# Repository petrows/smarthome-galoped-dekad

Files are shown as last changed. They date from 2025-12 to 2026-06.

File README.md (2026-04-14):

# Galoped-dekad

Vintage analog indicator with modern MCU and Tasmota.

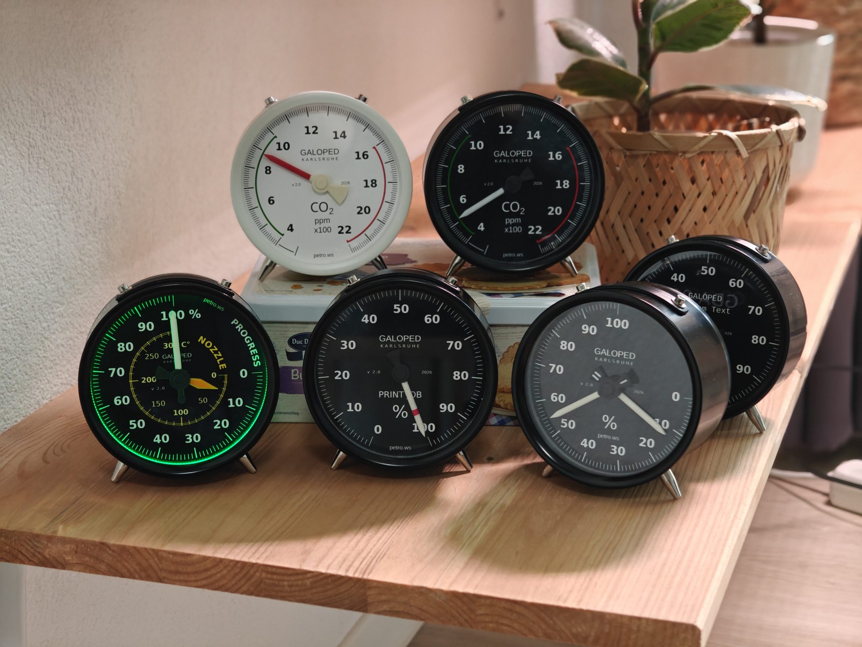
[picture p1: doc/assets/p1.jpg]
Device


This device is a universal desktop indicator with nice exterrior and full open source nature. Based on ESP32-WROOM32E SoC module, VID6608 automotive gauge driver and X27-168 automotive gauge stepper motor.

* Analog indication with needle, resolution is 3840 steps;
* Support to drive 2 motors within included PCB;
* On-board sensors support: SenseAir S8 for Co₂, BMP280+AHTO20 for Temperature, Pressure and Humidity readings and many others;
* WiFi connectivity;
* Backlight: dimmable retro-filament and addressed RGB supported;
* Easy customisation to display anything else, from internal or external data source;
* Designed to run Tasmota directly: WebUI, MQTT, Smart-home integration and etc;
* 3D Printers status readings (i.e. temperature and progress) and display - for BambuLab and Octoprint;

## Buy device

I have some devices available on Etsy: https://www.etsy.com/de-en/shop/PetroWSDE

## Device variants

Device has several veriants built:

* [CO2 and Cliamte instrument](doc/device-co2.md)
* [3D Printer temperature + progress](doc/device-3dp.md)

## Changelog

* Device version 1: [Version-1 history branch](https://github.com/petrows/smarthome-galoped-dekad/tree/Version-1)
* Device version 2: This readme

### Changes in Version 2:

* Complete new case parts with optimized design:
    * Backlight and main part are assembled before case installation (significally reduces assembly effort)
    * Improved structure stability
* Only one PCB for now is required, drive enclosure is part of case for now
* Fixed design issues for PCB (missing pulldown resistors, connectors redesign)
* New USB-C power socket with USB-C-C cables support
* Complete rework of RGB backlight, removed LED artifacts and glare
* Complete firmware rework (autoexec.bat is not required anymore, fully integrated logic and UI)

## Project information

* [How to configure device](doc/fw-config.md)
* [How to command device](doc/fw-command.md)

## Device components

This repo contains full sources for this device:

* [CAD and STL models for device enclosure](case)
* [Datasheets for all components used](datasheet)
* [Firmare sources and configuration](firmware)
* [Gauge graphics](gauge)
* [Device schematics](schematic)

### External components

* Metal enclosure and glass is taken from [Ikea Dekad](https://www.ikea.com/de/de/p/dekad-wecker-schwarz-30540479/)

### Backlight

* Retro backlight version: 3V flexible LED filament strip (300mm)
* RGB baklight version: 252 mm (40 LED's) of 2.7 mm WS2812b addressed led strip

I dont assembly Retro backlight version by default anymore. RGB Backlight looks and works better for now in version 2.

## PCB and Schematics

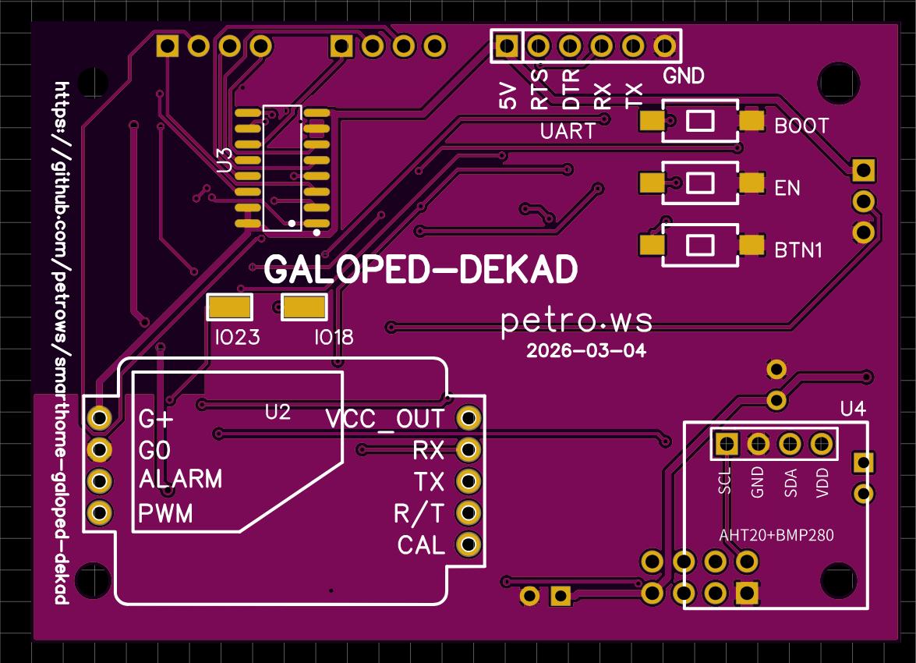
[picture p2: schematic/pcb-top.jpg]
PCB top


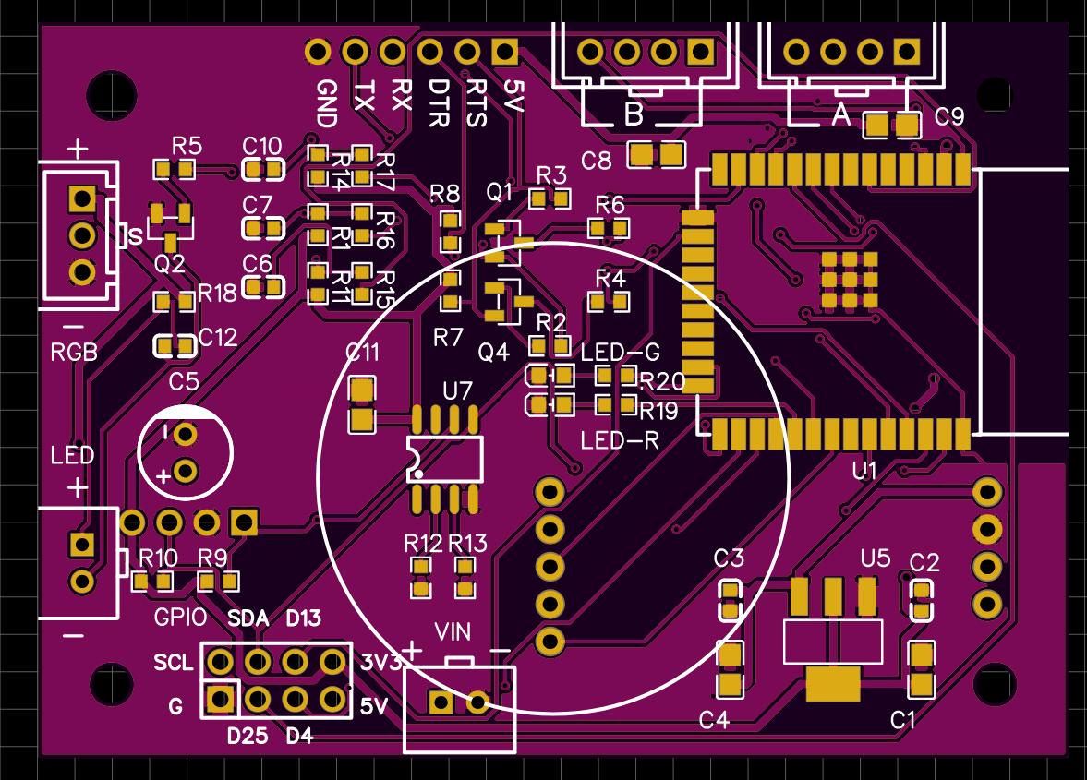
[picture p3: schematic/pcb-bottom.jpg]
PCB bottom


Made in EasyEDA Web project:

* [MCU board](https://oshwlab.com/petrows/galoped-dekad)

## Firmware

Firmware is based on [Tasmota](https://tasmota.github.io) with many features included.

Download actual version at [Releases](https://github.com/petrows/smarthome-galoped-dekad/releases) page.

Device configuration: [Galoped firmware configuration](doc/fw-config.md).

Scripts are in [firmware configuration files](firmware).

## Device strucutre

Physical parts are designed in FreeCAD and provided as-is with STL files to print:

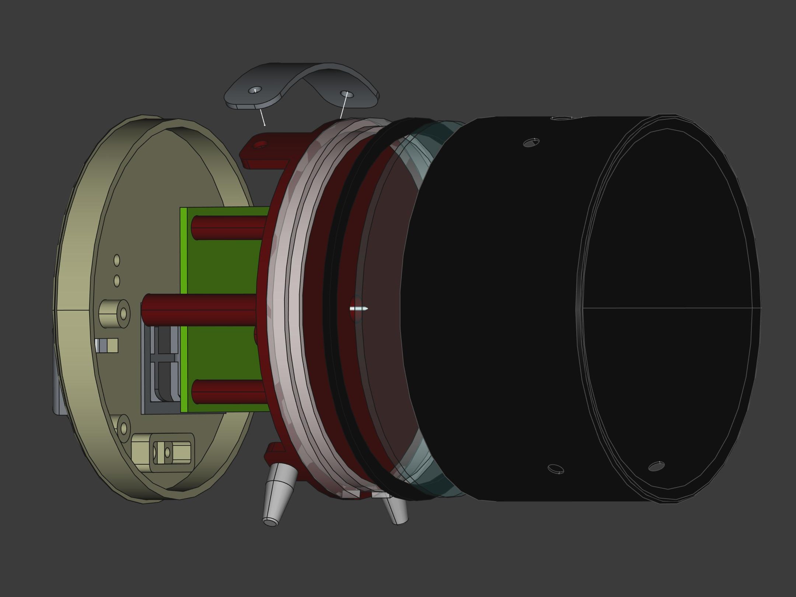
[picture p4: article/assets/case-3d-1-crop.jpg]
FreeCAD 3d view 1


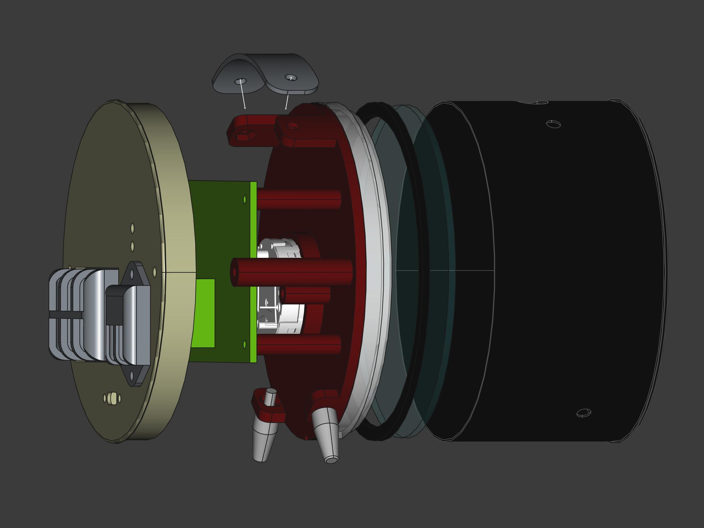
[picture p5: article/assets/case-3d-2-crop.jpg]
FreeCAD 3d view 2


## Assembly

See: [Assembly instructions](doc/assembly.md).

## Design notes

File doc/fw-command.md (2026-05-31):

# How to command device

This section describes, how to send commands to device.

## Primary gauge command

Original firmware defines new command `GalopedSetX Y`, where
`X` - gauge number starting from `1`, `Y` - target value *in gauge unuts*.

To use this command, device [Guage configuration](fw-config.md) is required.

Important: this command saves the state into FRAM memory (if present),
this is importnant to re-run correct zero procedure on power cycle.

Examples:

```ruby
# Set Gauge 1 to display 77% (units, i.e. percent, as defined in galoped.ini)
GalopedSet1 77

# Set Gauge 2 to display 32°C (units, i.e. degrees, as defined in galoped.ini)
GalopedSet2 32
```

Command can be issues via:

* Console (**Tools** -> **Console** or Serial console)
* Via HTTP, for example `http://<ip>/cm?cmnd=GalopedSet1%2023`
(use `%20` instead of space)
* MQTT

And other methods, see full list:
<https://tasmota.github.io/docs/Commands/#how-to-use-commands>

## Raw commands

Each unit has also raw commands to move: in steps or in procent from physical drive scale,
defined by VID6608 Tasmota driver. This commands ignore gauge settings in `galoped.ini`
and the **not** updating gauge position in FRAM - use with cauton.

Use following commands to control raw drive movement:

| Console Commands | Description | Values |
|---|---|---|
| `GaugeSet` | Set position in absolute steps | `0` - `3840`|
| `GaugeSetPercent`| Set position in percent | `0` - `100` |
| `GaugeZero` | Reset drive; optional argument is saved position | `0` - `3840`|

All commands have Drive suffix. If not set, it drives first motor. If set, it uses Drive number.
If suffix is `0` - it drives all motors. Examples:

* `GaugeZero3`: Reset drive number 3 with default reset routine;
* `GaugeZero2 751`: Reset drive number 2 with expected last position as `751`;
* `GaugeSet0 366`: Set all drives absolute position 366;
* `GaugeSetPercent 30`: Set drive number 1 position to 30%;

See full driver documentation here: <https://tasmota.github.io/docs/vid6608/> .

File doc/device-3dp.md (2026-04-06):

# Galoped (3D Printer version)

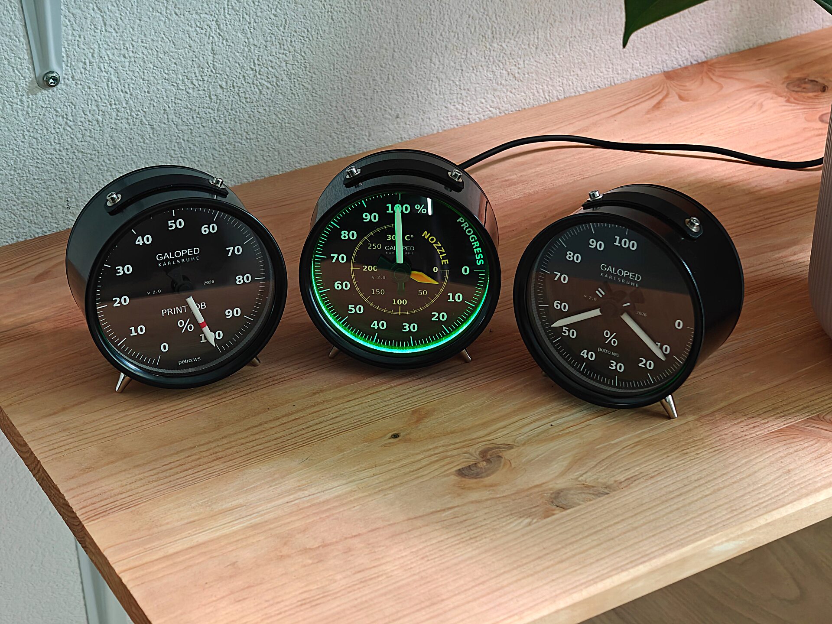
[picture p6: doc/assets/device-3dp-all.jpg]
Device


## Device specs

Device has customizations on top of base Galoped model:

* Device does not have any customization
* Sensors are not installed

## Configuration

Configuration for devices:

### Printer Temperature + Progress (Bi-Axial)

```ini
; galoped.ini
; Printer Temperature + Progress (Bi-Axial)
[galoped]
model = 3dp_tp
[gauge-1]
name = Temp
unit = C°
deg = 270
min = 0
max = 300
[gauge-2]
name = Progress
unit = %
deg = 270
min = 0
max = 100
```

## BambuLab printer status display

Firmware has module to read MQTT status report from BambuLab printers. To connect
such printer to gauge, you need to enable LAM mode and get Access key and know printer
address in LAN.

* [Enable developer mode in your printer](https://wiki.bambulab.com/en/knowledge-sharing/enable-developer-mode)
* Write down printer IP Address inside your home network
* Write down serial number of your printer

When done, you can configure Galoped's firmware to read data:

* Navigate to **Configuration** -> **Configure BambuLab**
* Enter required fields:
    * `Printer serial` - Serial number of your printer
    * `Printer IP` - Address of your printer in home network
    * `LAN Access code` - Access code for your printer

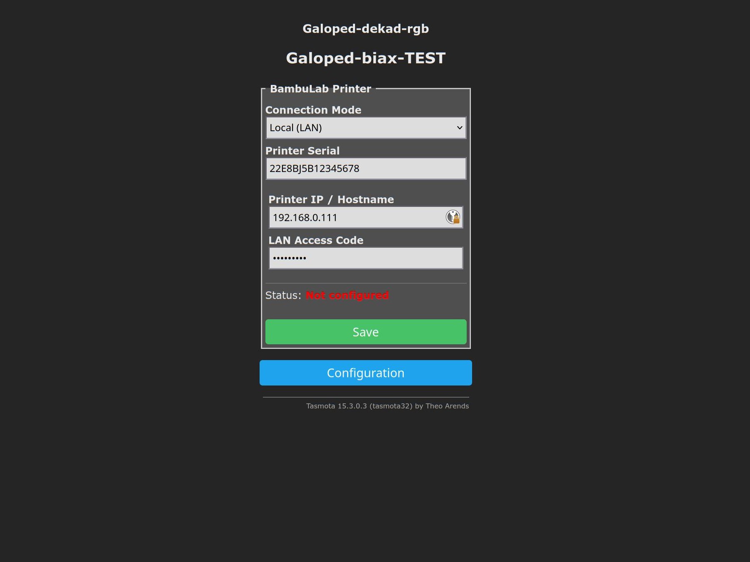
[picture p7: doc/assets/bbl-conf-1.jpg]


After configuration, please wait a few minutes, when data is read from printer,
you will see status at the index page:

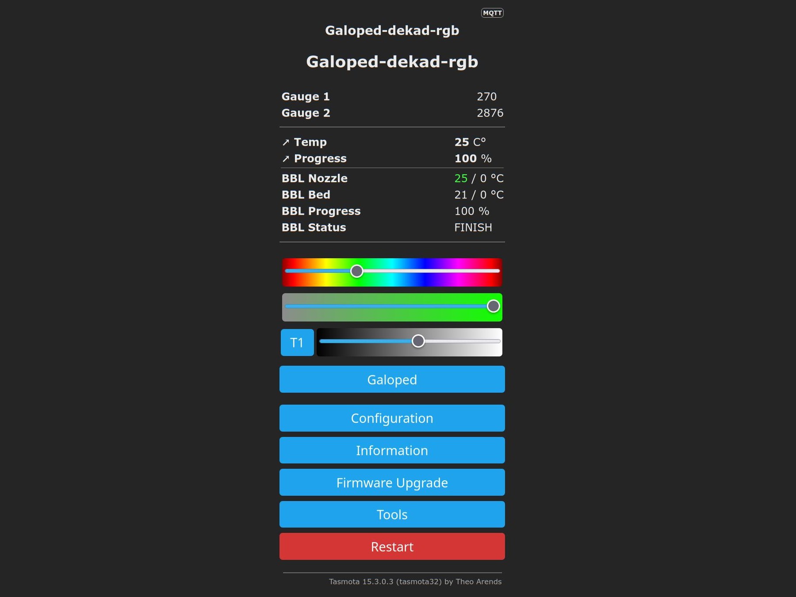
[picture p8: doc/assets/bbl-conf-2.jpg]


## Octoprint printer status display

Octoprint can be integrated using various ways.

Recommended option is to use common MQTT brocker and in this case you can configure Octoprint as follows:

```bash
# This command drives Gauge 1 to position 77%

mosquitto_pub -h <broker-ip> -u <username> -P <password> -t 'cmnd/galoped_ABCDEF/GalopedSet1' -m '77'
```

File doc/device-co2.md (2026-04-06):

# Galoped (CO2 version)

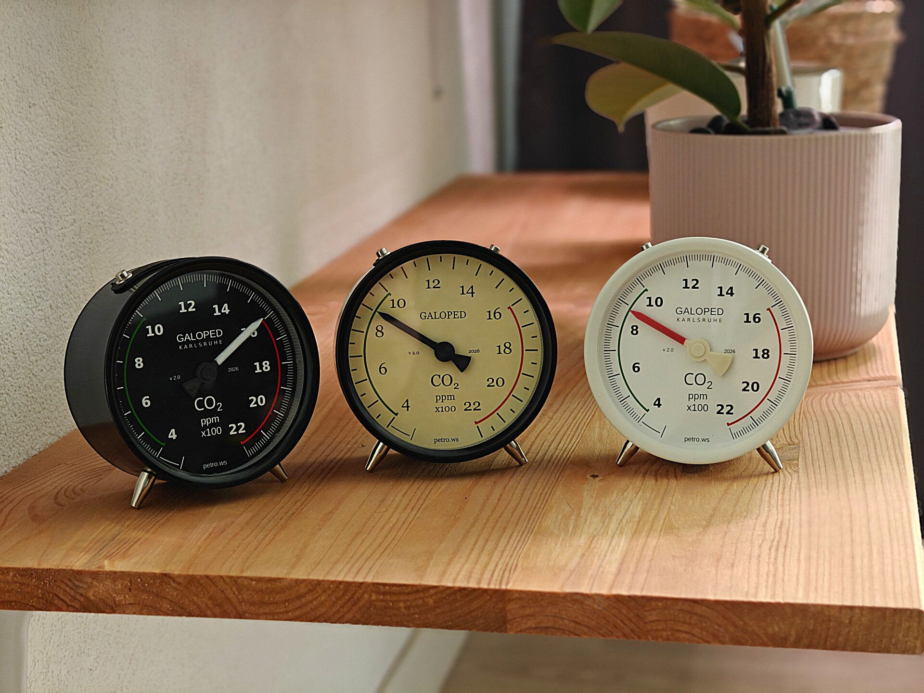
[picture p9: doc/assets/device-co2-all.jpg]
Device


## Device specs

Device has customizations on top of base Galoped model:

* On-board sensors: SenseAir S8 for Co₂, BMP280+AHTO20 for Temperature, Pressure and Humidity readings
* Backlight RGB can follow CO2 readings and indicate current green-yell-red state

## Configuration

Configuration for device:

```ini
; galoped.ini
; CO2 Meter
[galoped]
model = co2
[gauge-1]
name = CO2
unit = ppm
deg = 320
deg_dz = 15
min = 400
max = 2200
```

## RGB backlight for status

To enable RGB backlight auto-color option, navigate to "Configuration" -> "Configure Galoped" and select
"RGB Mode" to "Dynamic".

This will enable Backlight auto color, driven by current CO2 readings.

*Note:* Color can be still changed manually or via command, it will be updated
on next changed value received from sensor.

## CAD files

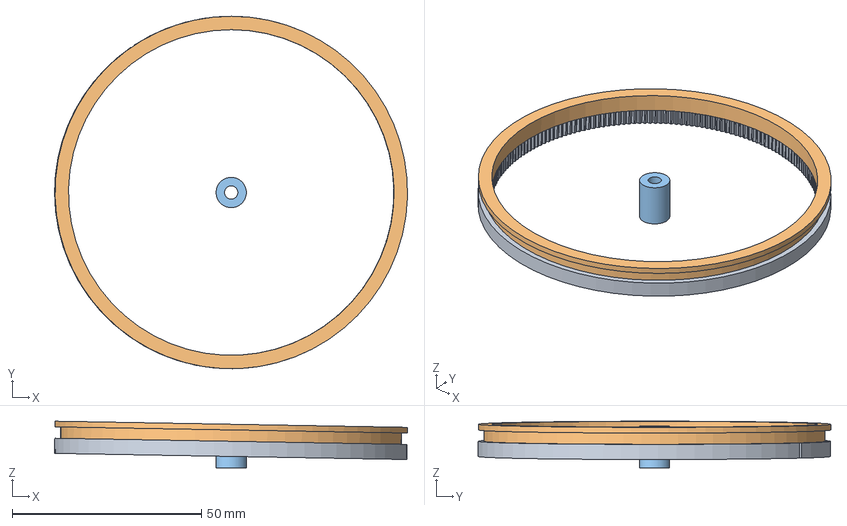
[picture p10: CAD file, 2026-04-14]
case/Galoped-case.FCStd
93.2 x 93.1 x 12.3 mm
Ring-rgb-base
Ring-rgb-cap
PCB-S-Temp-spacer

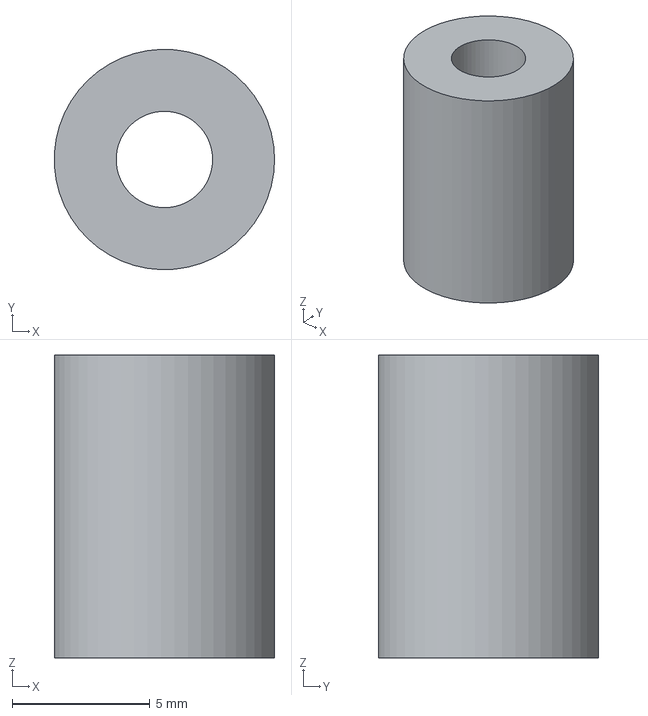
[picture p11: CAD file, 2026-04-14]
case/step/pcb-s-tmp-spacer.step
7.99 x 8.00 x 11.0 mm

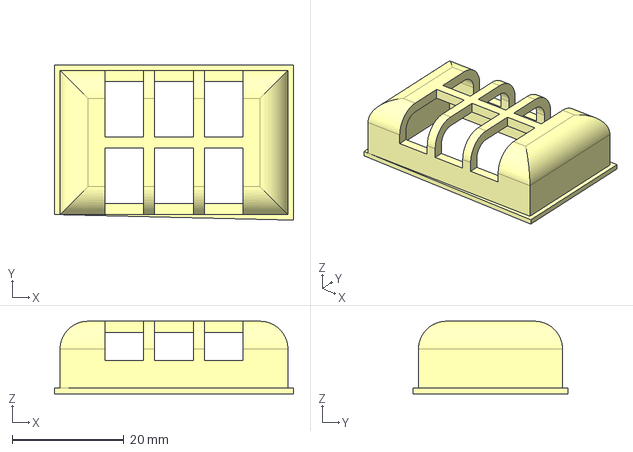
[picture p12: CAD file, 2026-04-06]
case/step/cover-s8.step
42.8 x 27.8 x 13.0 mm

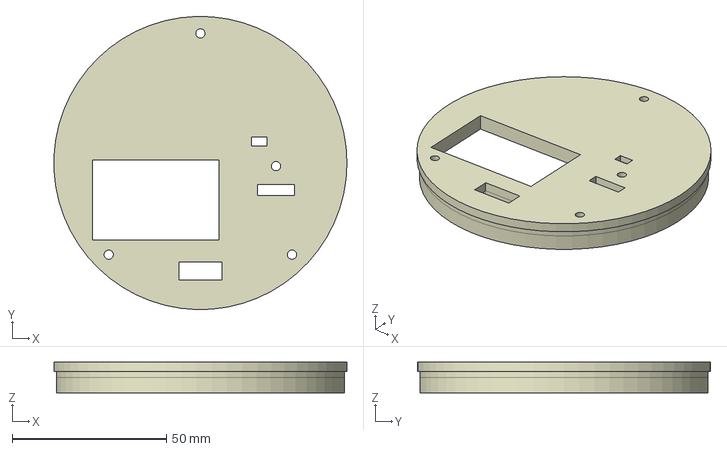
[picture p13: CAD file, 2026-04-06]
case/step/back.step
94.9 x 95.0 x 10.0 mm

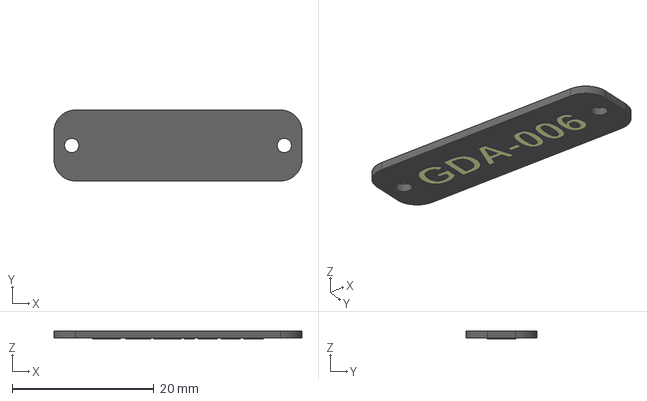
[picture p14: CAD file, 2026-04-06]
case/step/back-plate.step
35.0 x 10.00 x 1.10 mm
Plate-text-body

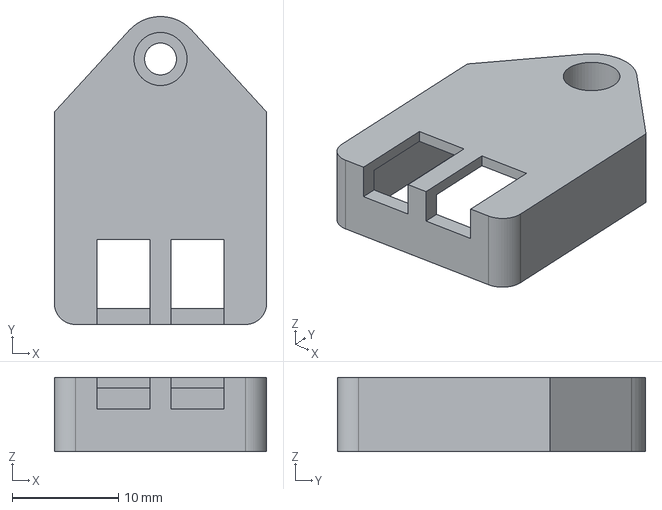
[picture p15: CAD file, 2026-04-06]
case/step/cover-climate.step
20.0 x 29.0 x 7.00 mm

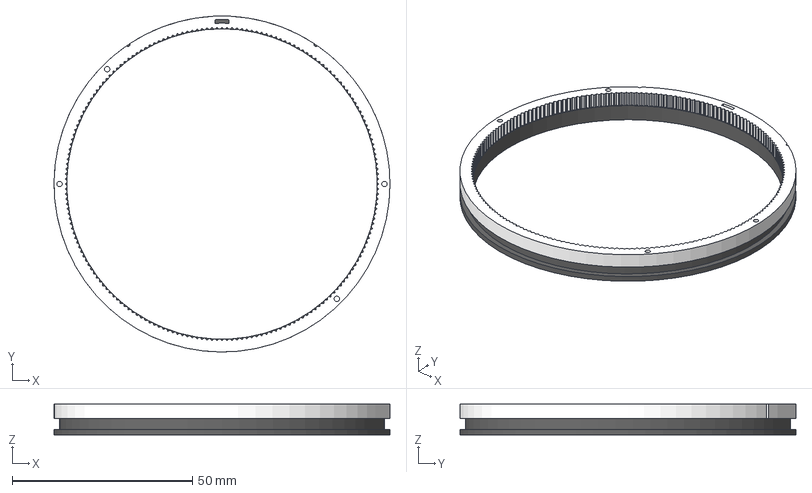
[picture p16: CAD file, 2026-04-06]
case/step/ring-rgb.step
93.1 x 93.1 x 8.50 mm
Ring-rgb-base
Ring-rgb-cap

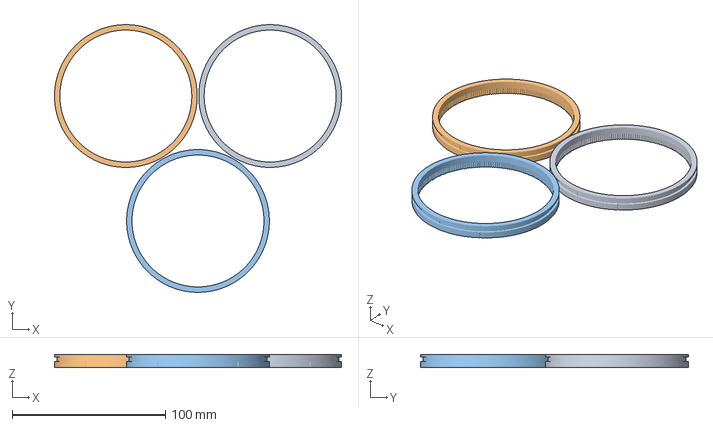
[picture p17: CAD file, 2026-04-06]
case/step/galoped-ring-rgb.3mf
187.2 x 174.6 x 8.50 mm
ring-rgb.step x 3

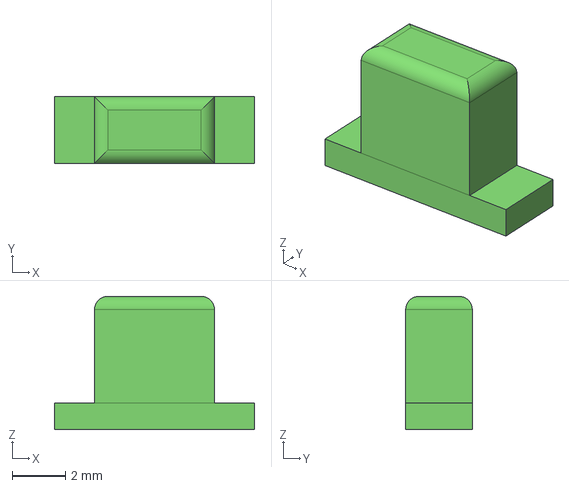
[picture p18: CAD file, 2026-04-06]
case/step/btn.step
7.50 x 2.50 x 5.00 mm

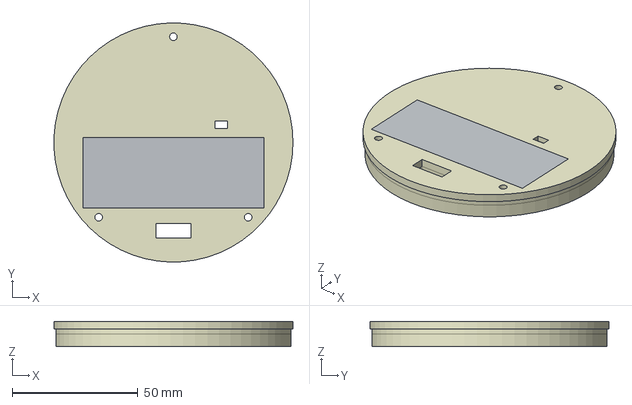
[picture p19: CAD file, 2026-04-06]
case/step/back-no-holes.step
94.9 x 95.0 x 10.0 mm
Back-main
Back-no-holes

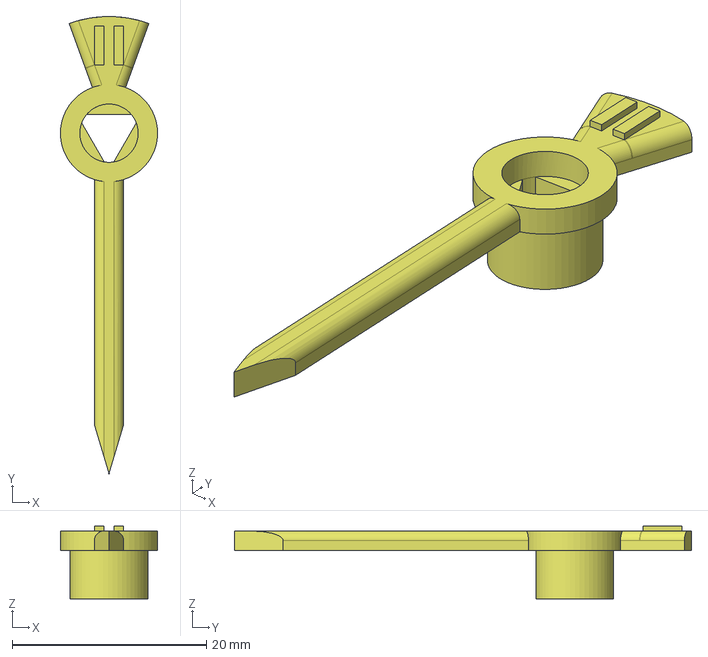
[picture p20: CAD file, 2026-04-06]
case/step/arrow-ds-down.step
10.00 x 47.0 x 7.50 mm

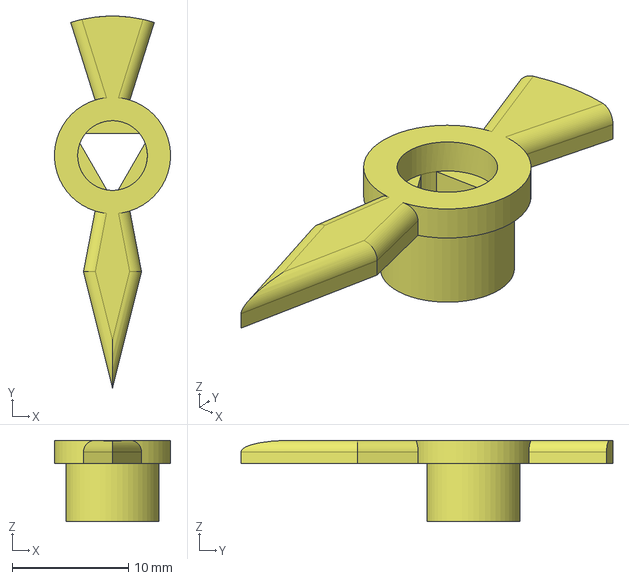
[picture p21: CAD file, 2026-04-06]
case/step/arrow-ds-alt-down.step
9.98 x 32.0 x 7.00 mm

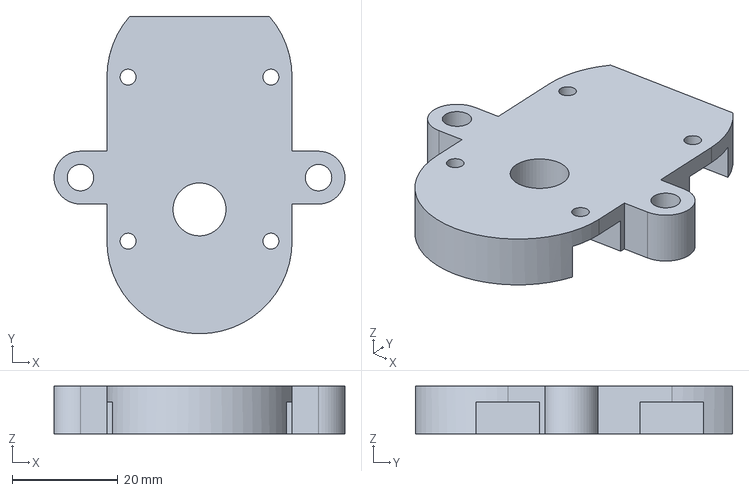
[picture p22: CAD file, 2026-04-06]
case/step/drive-double-offser.step
55.0 x 60.0 x 9.00 mm

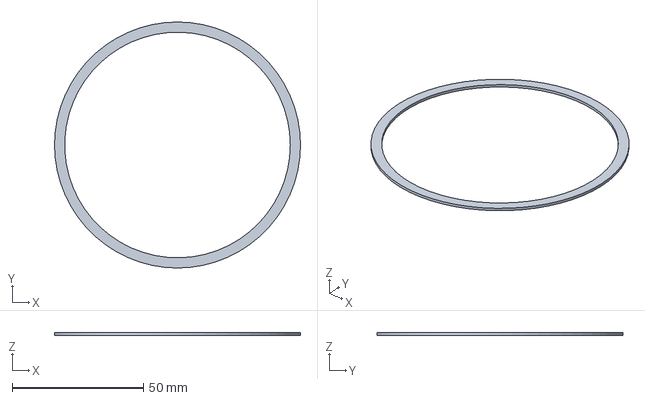
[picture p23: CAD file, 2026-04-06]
case/step/ring-cap.step
93.8 x 93.8 x 1.00 mm

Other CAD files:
case/Usb-conn.FCStd
case/step/drive-single-top.step
case/step/drive-double-top.step
case/step/top-label.step
case/step/arrow-double-down.step
case/step/arrow-double-top.step
case/step/arrow-ds-alt-top.step
case/step/arrow-ds-top.step
case/step/arrow-single.step
case/step/cover-s8.3mf
case/step/drive-single-offser.step
case/step/front.step
case/step/galoped-arrow.3mf
case/step/galoped-case.3mf
case/step/pcb.step
case/step/ring-retro.step

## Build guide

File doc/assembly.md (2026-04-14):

# Assembly

So, let's now connect everything together! Finally we'll see what kind of Frankenstein we've got here. We choose a configuration for assembly: Aviation style, lamp backlight, both sensors installed.

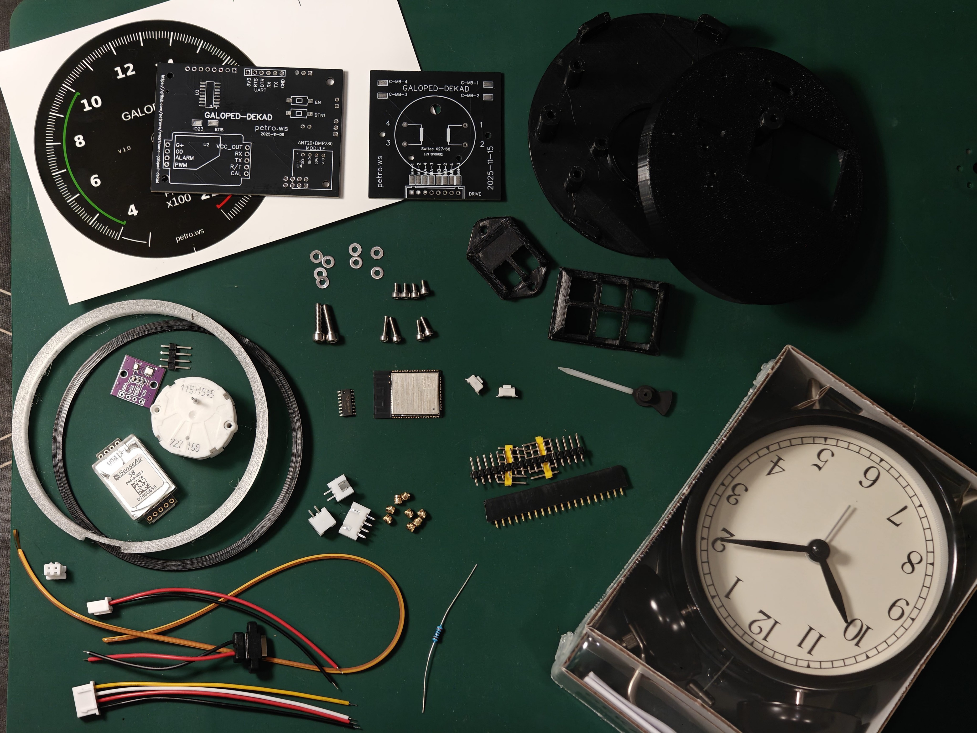
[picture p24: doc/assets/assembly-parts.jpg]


For assembly we should already have all the parts that remained from previous steps or findings. Or just print new ones on 3D and 2D printers, order boards, connectors, wires. We lay all this out on the table and admire. For assembly we generally need the following:

- IKEA DEKAD alarm clock
- Printed parts: front and back covers, top cover, CO₂ and climate sensor covers, two backlight frame parts
- Fasteners: M3 screws (2 pcs), M2 screws (10 pcs), Heat-set inserts for plastic M2 (10 pcs)
- [Filament backlight strip](https://www.aliexpress.com/item/1005009437951627.html) (26 cm or longer) and wires for it
- Printed circuit boards: main and motor
- [X27-168 motor](https://www.aliexpress.com/item/1005008385301163.html), leads on back side
- [ESP32-WROOM32E module (4Mb)](https://www.aliexpress.com/item/1005002515949841.html)
- [VID6608 chip](https://www.aliexpress.com/item/1005007050530920.html)
- [SenseAir S8 sensor](https://www.aliexpress.com/item/1005009122286447.html)
- [Climate sensor - AHT20 / BMP280 module](https://www.aliexpress.com/item/1005005486181411.html)
- [SMD buttons 3x6](https://www.aliexpress.com/item/1005009645342892.html), any height - I have 4.5 mm
- [JST-PH 2.54 connectors](https://www.aliexpress.com/item/1005008339053787.html) and wires: 2-pin (2 pcs), 4-pin (1 pc). I'm too lazy to crimp, got pre-crimped
- [USB-C power connector](https://www.aliexpress.com/item/1005010142667928.html)
- Wires, pin headers, soldering iron, good mood and determination :)

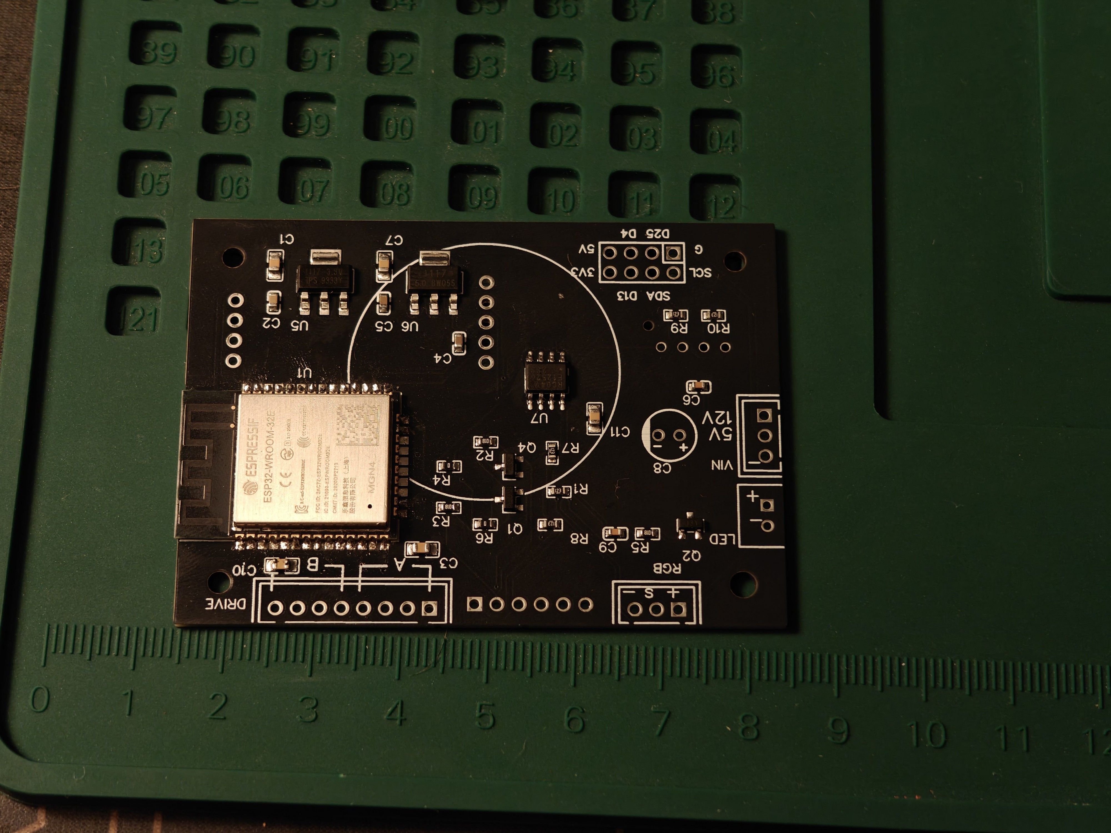
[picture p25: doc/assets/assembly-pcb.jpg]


First of all we install the ESP32 chip. I ordered without installation of it, because I had them and didn't want to risk possible defects. Then I cursed everything - installation is a brutal hassle, I ruined one module. Order installation at the factory together with the board - it will be the same price and much less hassle.

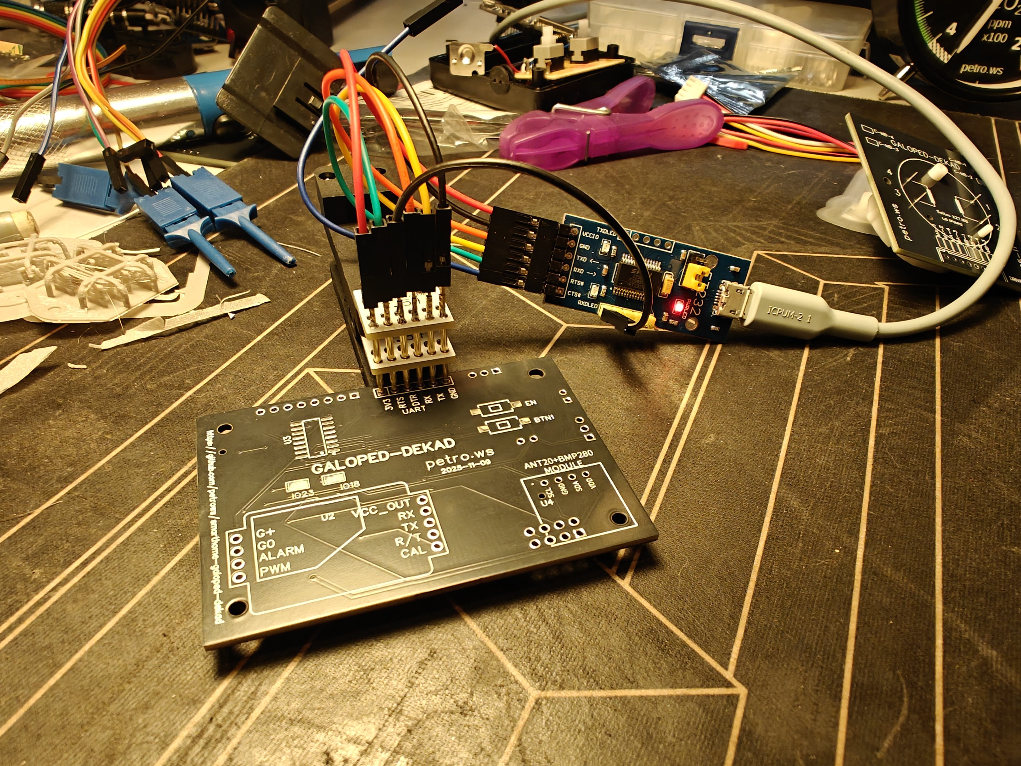
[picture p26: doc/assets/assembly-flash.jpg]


Immediately after installation it's important to check operability - flash the firmware and check that the device comes to consciousness. You can flash any Tasmota, then we'll flash what's needed over the air. I use [this adapter](https://www.aliexpress.com/item/1005008554998627.html), it has the needed RST and DTR outputs (note that DTR is brought out on the side header - I was stupid at first and confused it with CTS and ruined one board, thinking I did something improper). In this case the chip flashes directly through esptool or platform.io. If you don't have such an adapter, then any will do, main thing is it's compatible with 3.3V, short the contacts to enter flash mode manually then. It's better to supply external power - 3.3V in my version of the debug connector from the adapter was enough for flashing, but not enough for first boot anymore. In your board version this problem is solved (5V is brought out), but in any case external power is recommended - just in case. In this case connect only ground from the adapter, otherwise you can burn something.

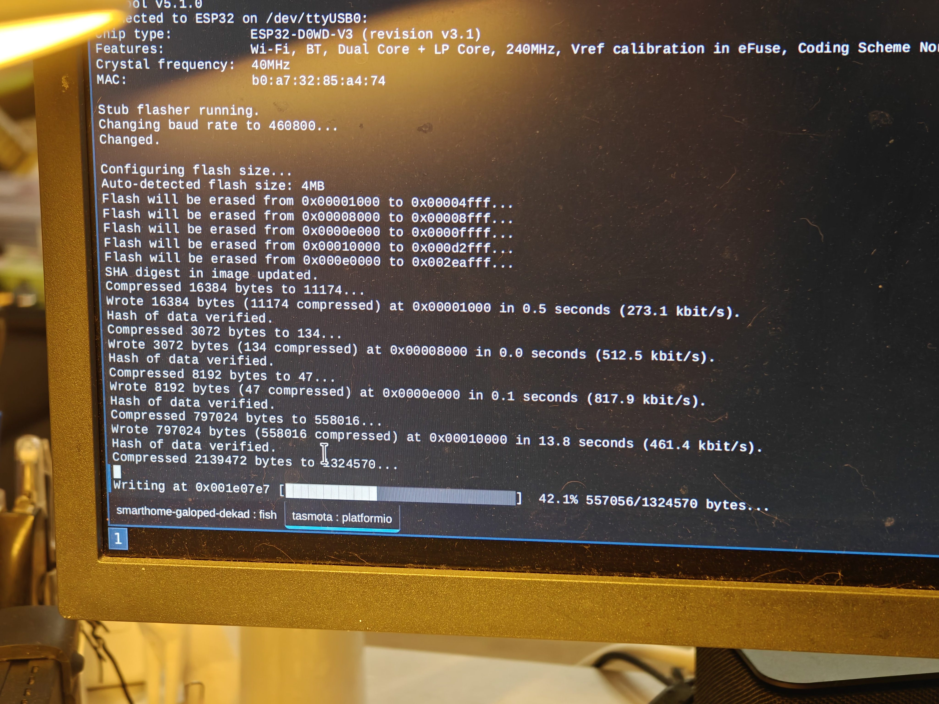
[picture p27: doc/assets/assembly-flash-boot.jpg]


Hooray! Seems we didn't ruin anything. Yet :)

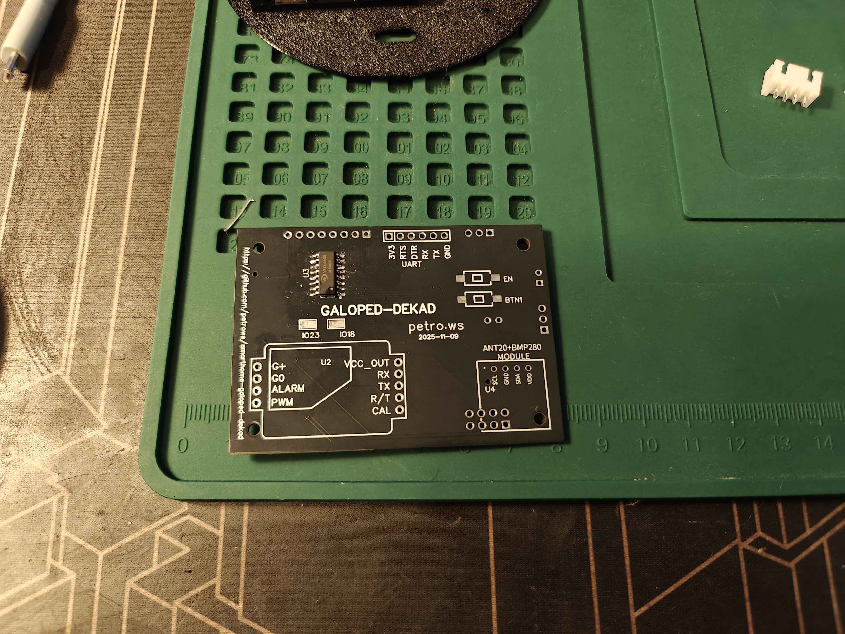
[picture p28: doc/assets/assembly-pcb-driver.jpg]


We solder the rest - connectors and actually our hero of the day - VID6608. It's much easier to install than ESP32, harder to mess up. Be sure to check pins after installation! Everything looked super for me, but half the pins actually weren't making contact. If poorly soldered it will look like this: the drive will jerk chaotically instead of smooth movement. We install everything else - button connectors and such.

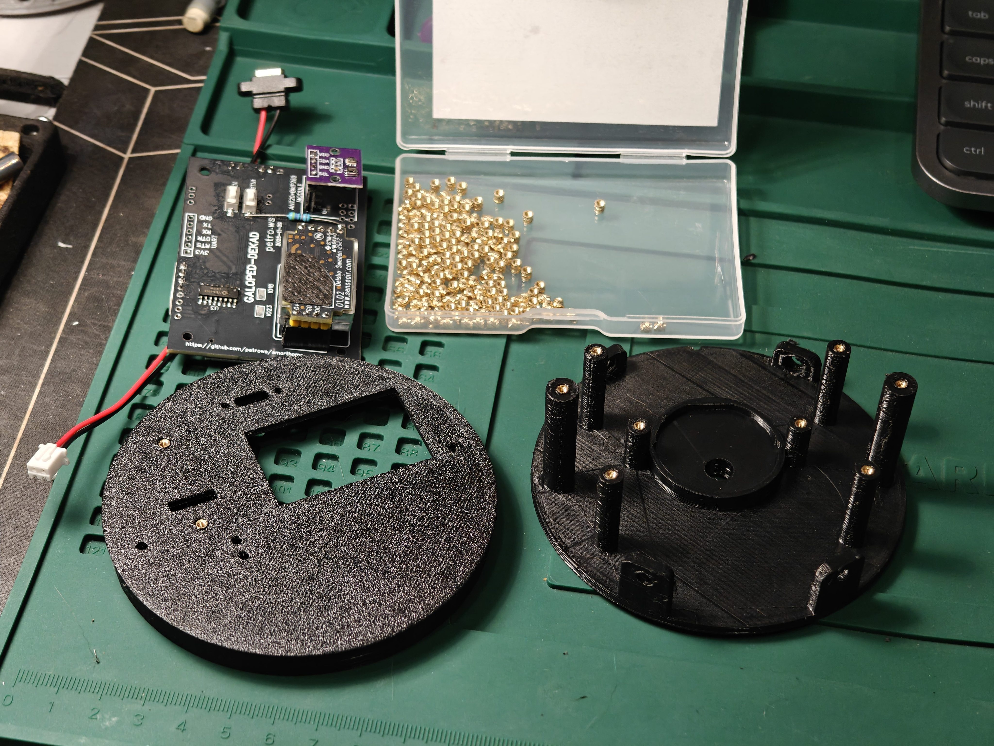
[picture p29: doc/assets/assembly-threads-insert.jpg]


We install sleeves for M2 screws. Installation is very simple - place on the hole and press in with soldering iron, everything turns out even and beautiful.

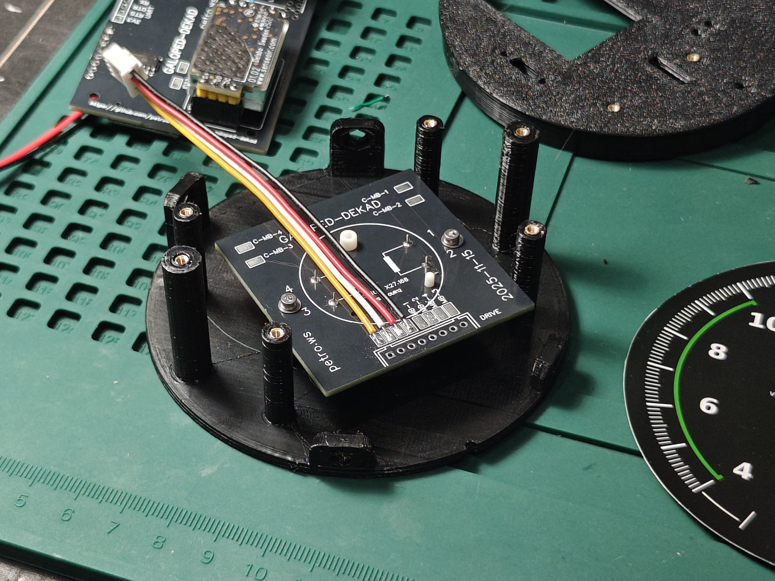
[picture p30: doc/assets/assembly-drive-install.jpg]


We solder our motor to the mounting board and put a connector. Holes for the header can be drilled out and push wires through there for better retention.

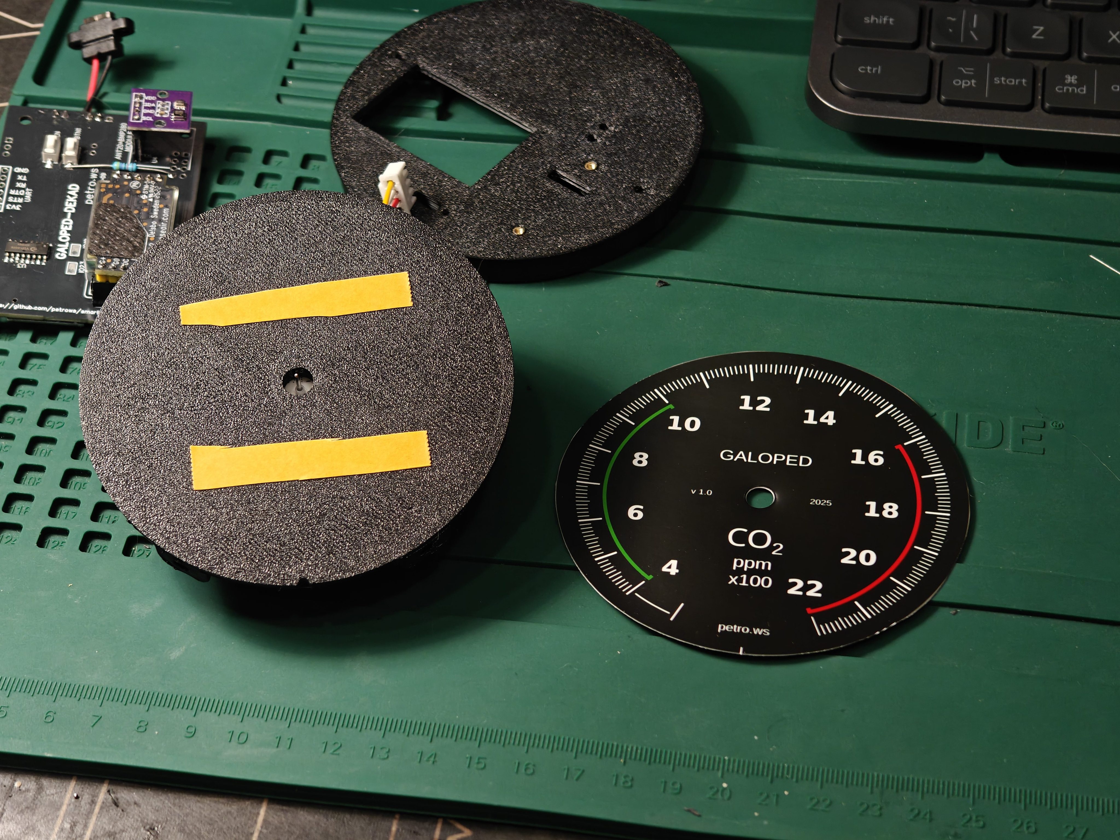
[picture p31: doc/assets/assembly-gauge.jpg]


After installing the drive we can cut out and glue the front panel. We prepare the needle, press the tip into it and paint. After this we can assemble everything together.

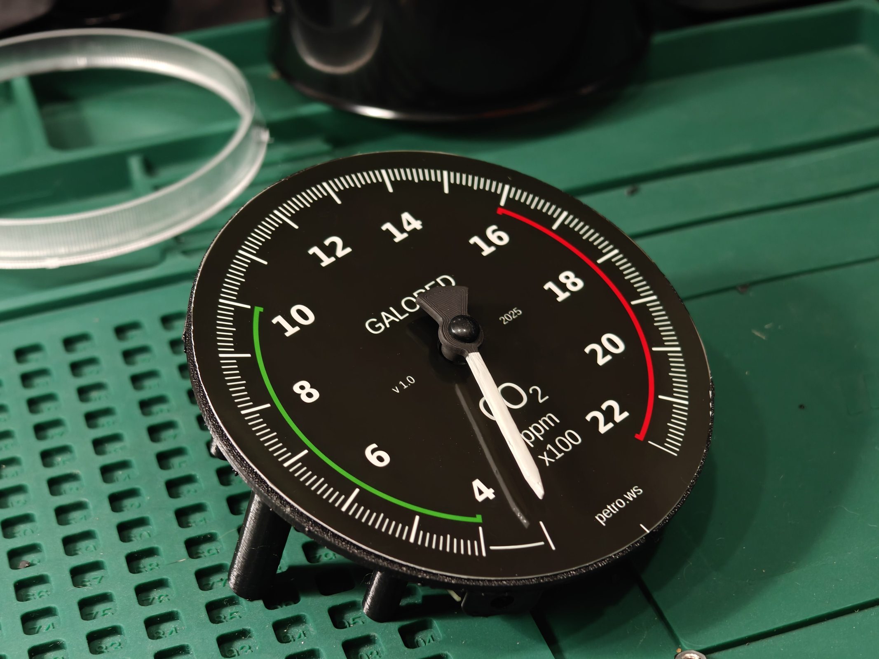
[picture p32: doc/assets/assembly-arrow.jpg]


At this stage it's important to set the needle exactly to zero. For this we pull the needle on as we can (it goes on very tight, don't be shy), then rotate the motor to the stop (without signal it rotates freely) to zero and carefully rotate the needle until it's exactly at the beginning of the dead zone, this is the true zero of the scale.

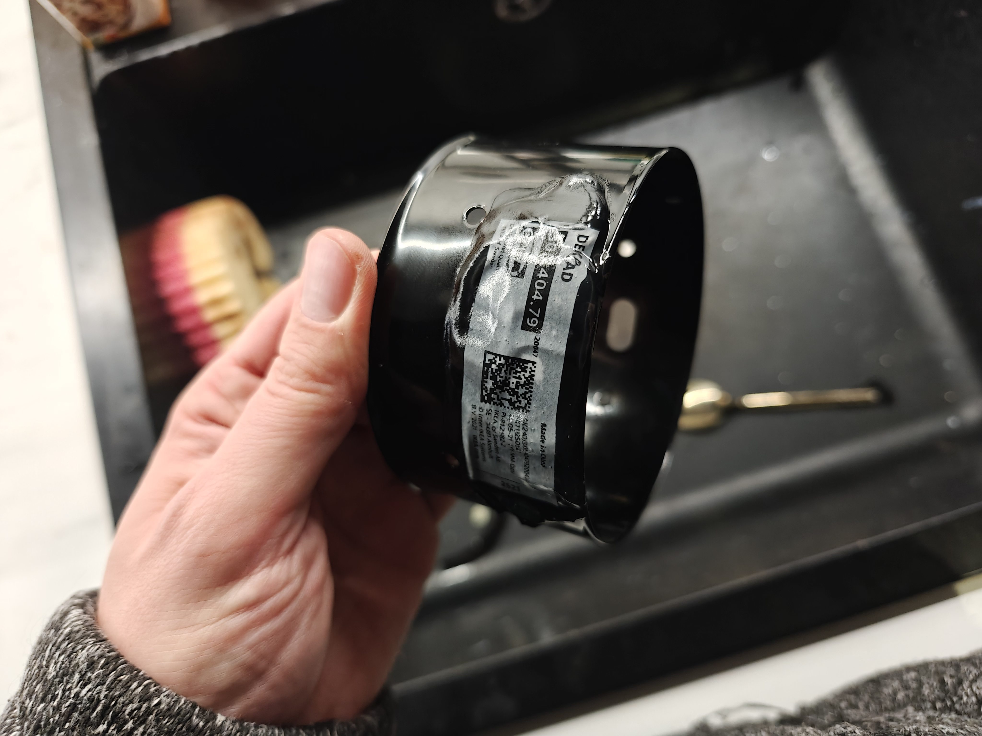
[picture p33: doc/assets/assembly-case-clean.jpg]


We disassemble the alarm clock, remove everything valuable from it, remove the sticker and clean. We get a beautiful glossy cylinder. We carefully remove the glass and preferably don't smudge it - greasy fingerprints will be hard to remove later.

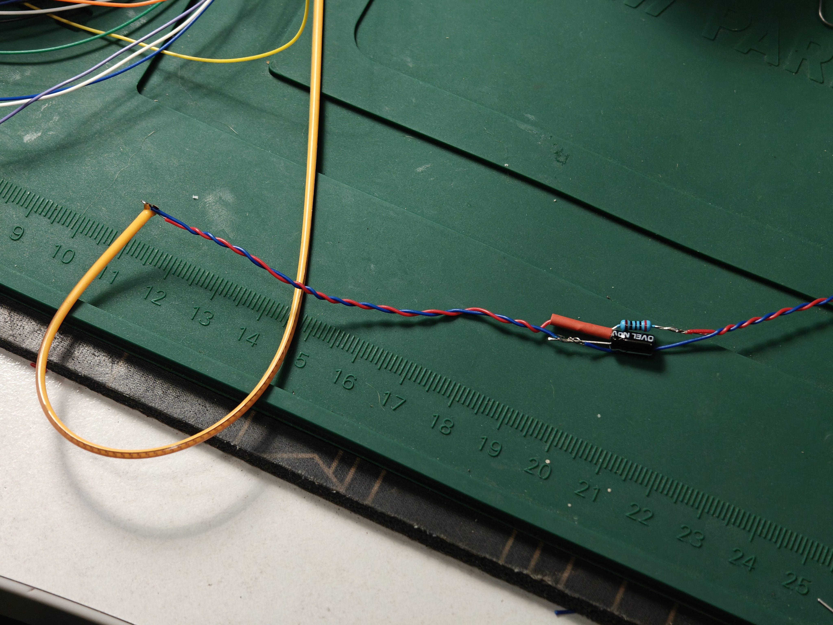
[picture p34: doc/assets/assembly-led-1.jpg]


We prepare the filament strip - solder to the leads at right angles and make a connector. I also have a correction circuit soldered: 220 Ohm resistor and ripple suppression capacitor. In the board version you'll see in EasyEDA these parts are already installed (at the time of creating the very first version I was still in doubt about the backlighting).

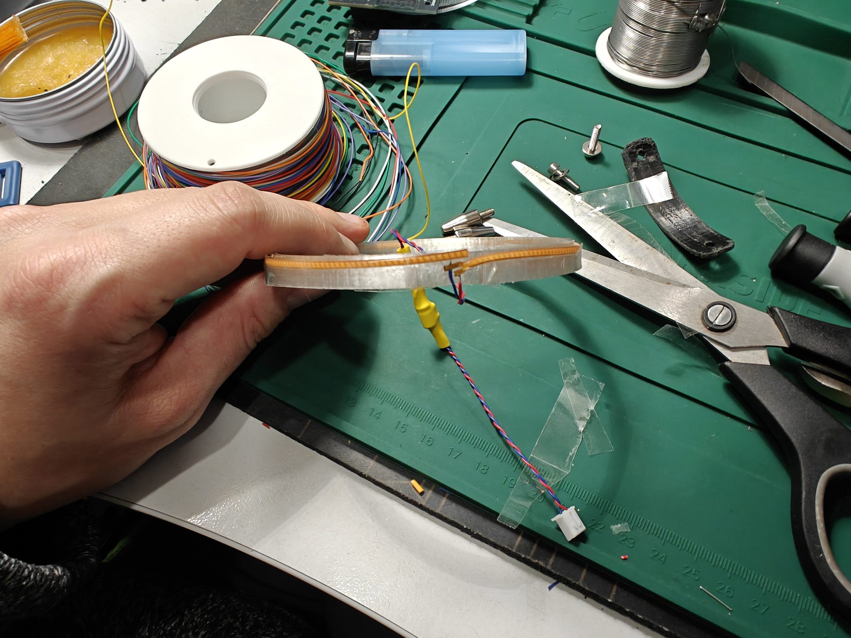
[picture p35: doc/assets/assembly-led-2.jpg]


We install the strip in the frame, it's best to turn it with the "matte" part inward. For convenience you can glue with transparent tape. Also put a bit of tape between the contact petals for insulation, there's no room to properly fit in heat shrink. We trim the strip so it meets evenly - then we'll have minimal dark piece of backlighting.

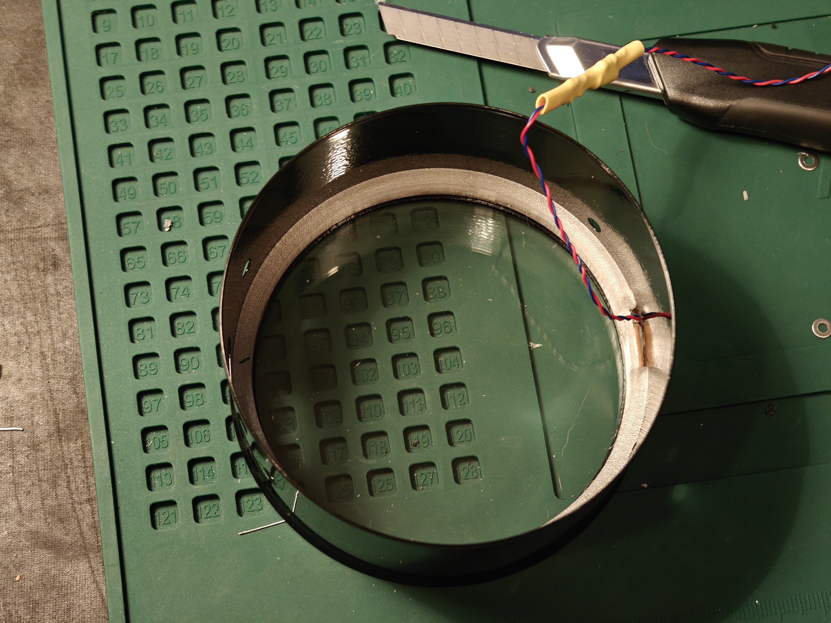
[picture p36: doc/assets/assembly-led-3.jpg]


We insert the glass, black frame and our frame with strip into the case. It's important to put in correct orientation - parts are made to enter tight fit (so nothing rattles) and rotating later can be difficult. Wires should exit exactly at the bottom center to get into the cutout of the main part.

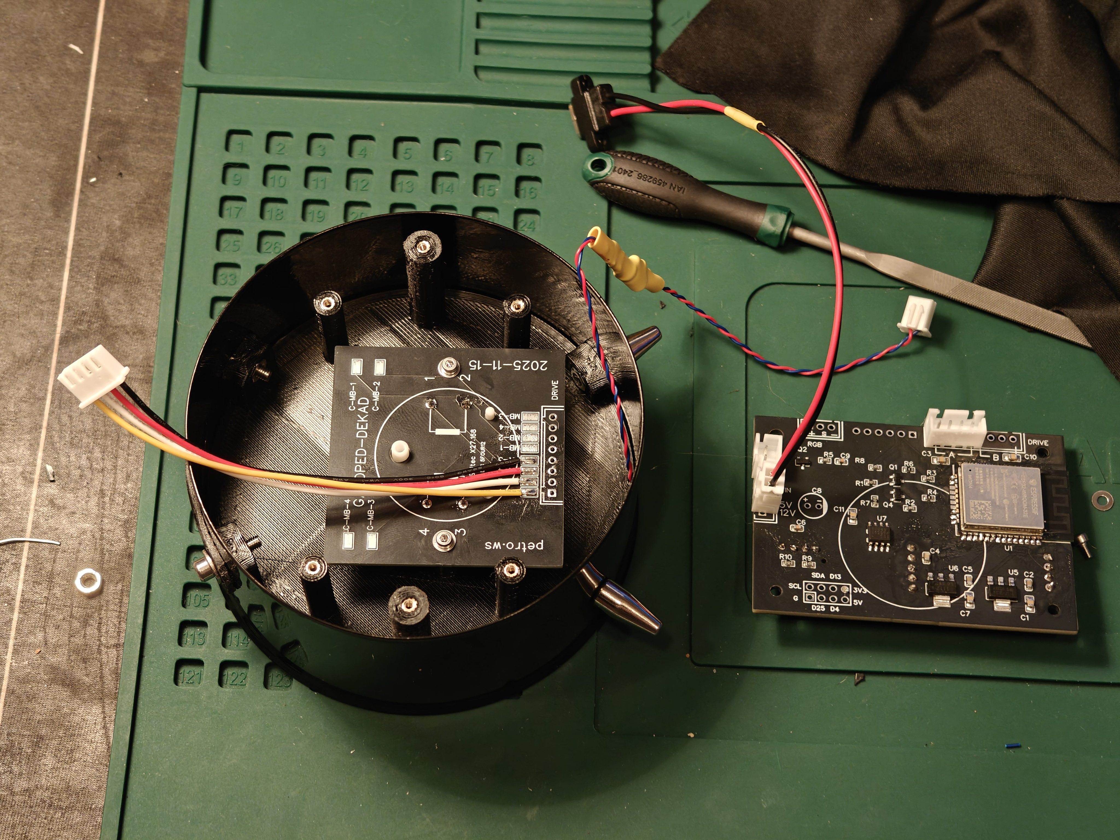
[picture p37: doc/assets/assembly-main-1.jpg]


We install the main case part, pass backlight wires through. Now we can screw in our main fastening lines: feet and M3 screws through the top cover.

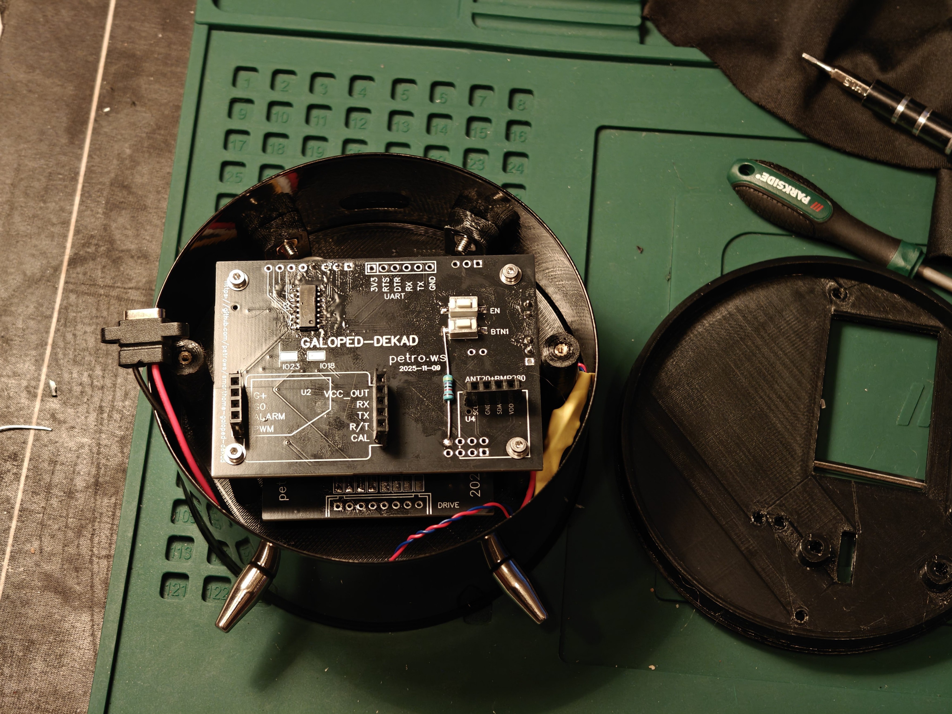
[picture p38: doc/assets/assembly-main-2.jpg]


We connect all connectors and install the main board, orient it with sensors down. We screw everything with beautiful M2 screws.

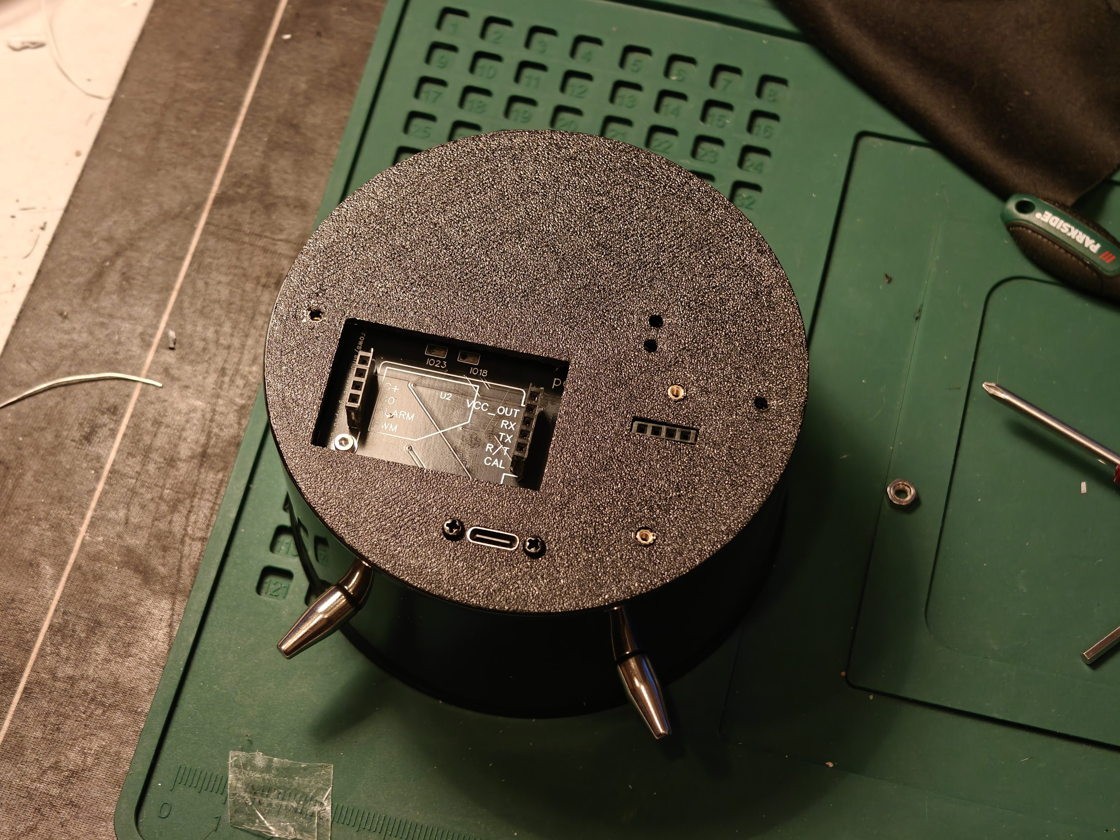
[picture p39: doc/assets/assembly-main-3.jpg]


In the back cover we screw the USB-C connector on small screws, pushing it from inside. You can use original silver IKEA ones from the alarm clock, but I have anodized black ones, they look better. We install the S8 sensor grille, the sensor itself and place the cover in place, screw everything on two M2 screws.

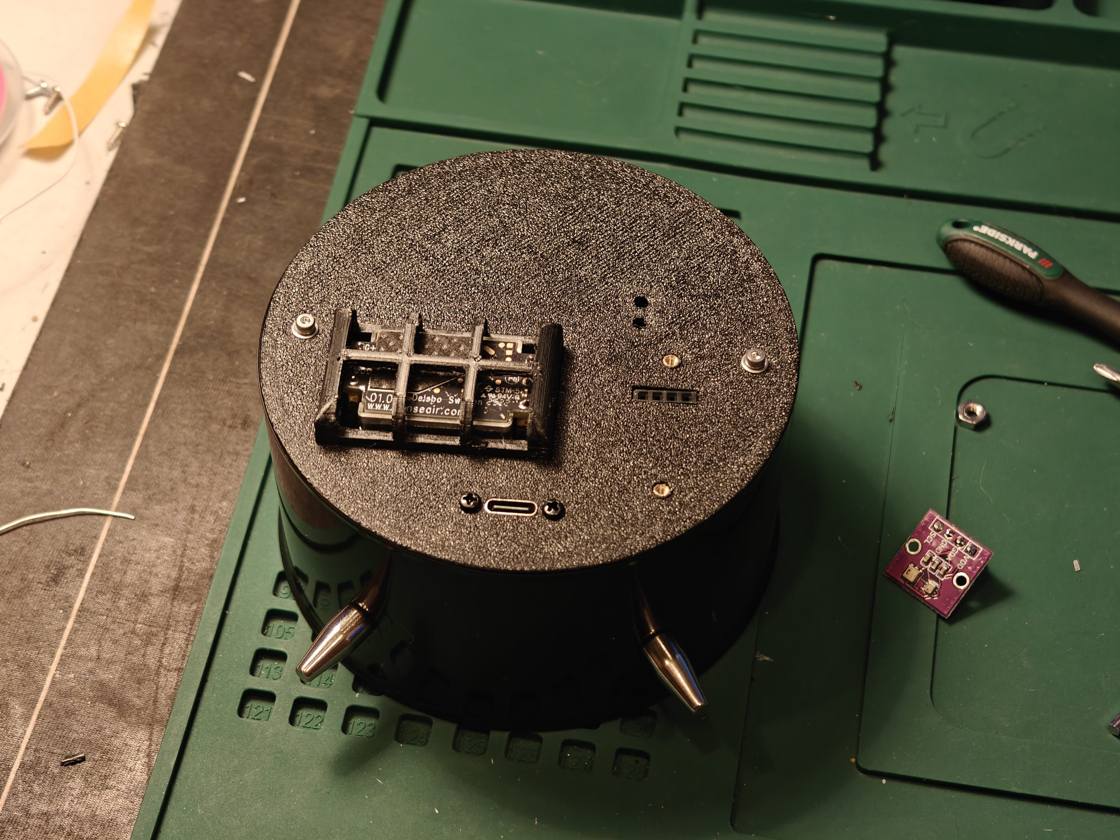
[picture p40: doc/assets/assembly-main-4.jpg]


Our climate sensor turns out sticking out of the case. This is good - then heat from the MCU won't affect its readings.

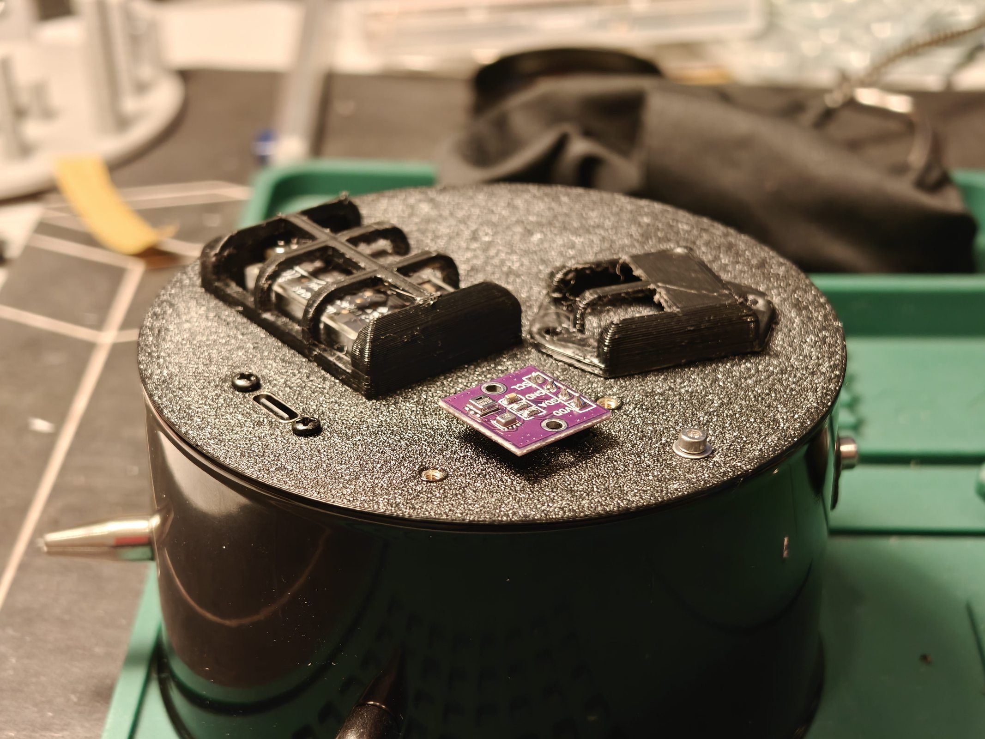
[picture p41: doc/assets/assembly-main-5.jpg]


We poke our climate sensor on the connector and screw the cover on top with two more M2 screws. Assembly complete :-)

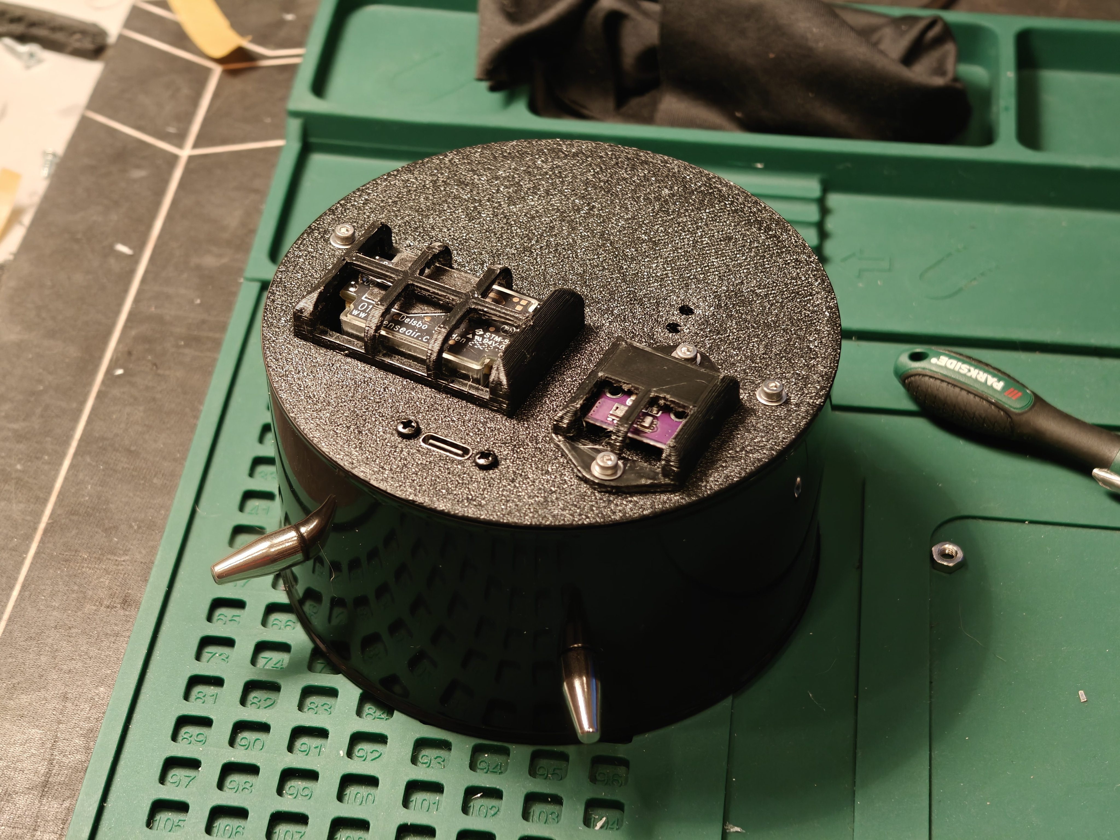
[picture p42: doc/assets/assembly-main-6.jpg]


We move to arm's length distance, turn on and check that everything works. Note that without initial configuration the device won't even call calibration "out of the box", we need to configure Tasmota and prepare the unit for work.

Assembly done.

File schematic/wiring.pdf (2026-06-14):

CONN

UP
(B)
270°

BACKSIDE VIEW
(Shaft behind)

BACKSIDE VIEW
(Shaft behind)

DOWN
(A)
320°

SINGLE
(A)
320°

This wiring makes direction with zero LEFT. To get Zero at RIGHT: mirror wiring horizontally

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
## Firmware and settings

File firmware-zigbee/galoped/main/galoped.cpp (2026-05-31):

/**
 * @file galoped.cpp
 * @author Petr Golovachev (petro@petro.ws)
 * @brief Galoped Zigbee firmware entry point
 */

#include "esp_check.h"
#include "esp_log.h"
#include "esp_zigbee_core.h"
#include "ha/esp_zigbee_ha_standard.h"
#include "nvs_flash.h"

#include "freertos/FreeRTOS.h"
#include "freertos/task.h"

#include "button.h"
#include "climate_sensor.h"
#include "rgb_led.h"
#include "senseair_s8.h"
#include "esp32_vid6608_rmt.h"

#include <cmath>
#include <memory>

static const char *TAG = "GLP";

namespace
{

constexpr gpio_num_t BUTTON_GPIO = static_cast<gpio_num_t>(CONFIG_GALOPED_BUTTON_GPIO);
constexpr gpio_num_t LED_GPIO = static_cast<gpio_num_t>(CONFIG_GALOPED_LED_GPIO);
constexpr uint32_t LED_COUNT = CONFIG_GALOPED_LED_COUNT;
constexpr uint8_t HA_ENDPOINT = 10;
constexpr uint32_t LONG_PRESS_MS = 3000;

// ZCL character strings are length-prefixed (first byte = length)
constexpr char MANUFACTURER_NAME[] =
    "\x07"
    "galoped";
constexpr char MODEL_IDENTIFIER[] =
    "\x07"
    "galoped";

std::unique_ptr<RgbLed> g_led;
std::unique_ptr<Button> g_button;
std::unique_ptr<esp32_vid6608_rmt> g_drive_1;
std::unique_ptr<esp32_vid6608_rmt> g_drive_2;
#if GALOPED_CLIMATE
std::unique_ptr<ClimateSensor> g_climate;
#endif
#if GALOPED_CO2
std::unique_ptr<SenseAirS8> g_co2;
#endif

#if GALOPED_CLIMATE
// --- Climate sensor Zigbee endpoint ----------------------------------------
constexpr gpio_num_t I2C_SDA_GPIO = static_cast<gpio_num_t>(CONFIG_GALOPED_I2C_SDA_GPIO);
constexpr gpio_num_t I2C_SCL_GPIO = static_cast<gpio_num_t>(CONFIG_GALOPED_I2C_SCL_GPIO);
constexpr uint8_t CLIMATE_ENDPOINT = 30;
constexpr uint32_t CLIMATE_REPORT_PERIOD_MS = 30000;

void add_climate_endpoint(esp_zb_ep_list_t *ep_list)
{
    esp_zb_basic_cluster_cfg_t basic_cfg = {
        .zcl_version = ESP_ZB_ZCL_BASIC_ZCL_VERSION_DEFAULT_VALUE,
        .power_source = ESP_ZB_ZCL_BASIC_POWER_SOURCE_MAINS_SINGLE_PHASE,
    };
    esp_zb_attribute_list_t *basic = esp_zb_basic_cluster_create(&basic_cfg);
    esp_zb_basic_cluster_add_attr(basic, ESP_ZB_ZCL_ATTR_BASIC_MANUFACTURER_NAME_ID,
                                  const_cast<char *>(MANUFACTURER_NAME));
    esp_zb_basic_cluster_add_attr(basic, ESP_ZB_ZCL_ATTR_BASIC_MODEL_IDENTIFIER_ID,
                                  const_cast<char *>(MODEL_IDENTIFIER));

    esp_zb_identify_cluster_cfg_t identify_cfg = {.identify_time = 0};
    esp_zb_attribute_list_t *identify = esp_zb_identify_cluster_create(&identify_cfg);

    // 0x8000 = "invalid/unknown" sentinel per ZCL spec
    esp_zb_temperature_meas_cluster_cfg_t temp_cfg = {
        .measured_value = static_cast<int16_t>(0x8000),
        .min_value = -4000,  // -40 °C in 0.01 °C
        .max_value = 8500,   //  85 °C
    };
    esp_zb_attribute_list_t *temp = esp_zb_temperature_meas_cluster_create(&temp_cfg);

    esp_zb_humidity_meas_cluster_cfg_t hum_cfg = {
        .measured_value = 0xFFFF,
        .min_value = 0,
        .max_value = 10000,  // 100.00 % RH
    };
    esp_zb_attribute_list_t *hum = esp_zb_humidity_meas_cluster_create(&hum_cfg);

    esp_zb_pressure_meas_cluster_cfg_t pres_cfg = {
        .measured_value = static_cast<int16_t>(0x8000),
        .min_value = 300,
        .max_value = 1100,
    };
    esp_zb_attribute_list_t *pres = esp_zb_pressure_meas_cluster_create(&pres_cfg);

    esp_zb_cluster_list_t *clusters = esp_zb_zcl_cluster_list_create();
    esp_zb_cluster_list_add_basic_cluster(clusters, basic, ESP_ZB_ZCL_CLUSTER_SERVER_ROLE);
    esp_zb_cluster_list_add_identify_cluster(clusters, identify, ESP_ZB_ZCL_CLUSTER_SERVER_ROLE);
    esp_zb_cluster_list_add_temperature_meas_cluster(clusters, temp, ESP_ZB_ZCL_CLUSTER_SERVER_ROLE);
    esp_zb_cluster_list_add_humidity_meas_cluster(clusters, hum, ESP_ZB_ZCL_CLUSTER_SERVER_ROLE);
    esp_zb_cluster_list_add_pressure_meas_cluster(clusters, pres, ESP_ZB_ZCL_CLUSTER_SERVER_ROLE);

    esp_zb_endpoint_config_t ep_cfg = {
        .endpoint = CLIMATE_ENDPOINT,
        .app_profile_id = ESP_ZB_AF_HA_PROFILE_ID,
        .app_device_id = ESP_ZB_HA_TEMPERATURE_SENSOR_DEVICE_ID,
        .app_device_version = 0,
    };
    esp_zb_ep_list_add_ep(ep_list, clusters, ep_cfg);
}

void climate_task(void *)
{
    while (true) {
        if (g_climate) {
            auto r = g_climate->read();

            if (esp_zb_lock_acquire(pdMS_TO_TICKS(500))) {
                if (r.temp_valid) {
                    int16_t v = static_cast<int16_t>(r.temperature_c * 100.0f);
                    esp_zb_zcl_set_attribute_val(CLIMATE_ENDPOINT, ESP_ZB_ZCL_CLUSTER_ID_TEMP_MEASUREMENT,
                                                 ESP_ZB_ZCL_CLUSTER_SERVER_ROLE,
                                                 ESP_ZB_ZCL_ATTR_TEMP_MEASUREMENT_VALUE_ID, &v, false);
                }
                if (r.humidity_valid) {
                    uint16_t v = static_cast<uint16_t>(r.humidity_pct * 100.0f);
                    esp_zb_zcl_set_attribute_val(CLIMATE_ENDPOINT, ESP_ZB_ZCL_CLUSTER_ID_REL_HUMIDITY_MEASUREMENT,
                                                 ESP_ZB_ZCL_CLUSTER_SERVER_ROLE,
                                                 ESP_ZB_ZCL_ATTR_REL_HUMIDITY_MEASUREMENT_VALUE_ID, &v, false);
                }
                if (r.pressure_valid) {
                    int16_t v = static_cast<int16_t>(r.pressure_hpa);
                    esp_zb_zcl_set_attribute_val(CLIMATE_ENDPOINT, ESP_ZB_ZCL_CLUSTER_ID_PRESSURE_MEASUREMENT,
                                                 ESP_ZB_ZCL_CLUSTER_SERVER_ROLE,
                                                 ESP_ZB_ZCL_ATTR_PRESSURE_MEASUREMENT_VALUE_ID, &v, false);
                }
                esp_zb_lock_release();
                ESP_LOGI(TAG, "Climate: T=%.2f°C H=%.1f%% P=%.1fhPa", r.temperature_c, r.humidity_pct, r.pressure_hpa);
            }
        }
        vTaskDelay(pdMS_TO_TICKS(CLIMATE_REPORT_PERIOD_MS));
    }
}
// ---------------------------------------------------------------------------
#endif  // GALOPED_CLIMATE

#if GALOPED_CO2
// --- SenseAir S8 CO2 sensor Zigbee endpoint --------------------------------
constexpr gpio_num_t S8_TX_GPIO = static_cast<gpio_num_t>(CONFIG_GALOPED_S8_UART_TX_GPIO);
constexpr gpio_num_t S8_RX_GPIO = static_cast<gpio_num_t>(CONFIG_GALOPED_S8_UART_RX_GPIO);
constexpr uart_port_t S8_UART_PORT = UART_NUM_1;
constexpr uint8_t CO2_ENDPOINT = 40;
constexpr uint32_t CO2_REPORT_PERIOD_MS = 30000;

void add_co2_endpoint(esp_zb_ep_list_t *ep_list)
{
    esp_zb_basic_cluster_cfg_t basic_cfg = {
        .zcl_version = ESP_ZB_ZCL_BASIC_ZCL_VERSION_DEFAULT_VALUE,
        .power_source = ESP_ZB_ZCL_BASIC_POWER_SOURCE_MAINS_SINGLE_PHASE,
    };
    esp_zb_attribute_list_t *basic = esp_zb_basic_cluster_create(&basic_cfg);
    esp_zb_basic_cluster_add_attr(basic, ESP_ZB_ZCL_ATTR_BASIC_MANUFACTURER_NAME_ID,
                                  const_cast<char *>(MANUFACTURER_NAME));
    esp_zb_basic_cluster_add_attr(basic, ESP_ZB_ZCL_ATTR_BASIC_MODEL_IDENTIFIER_ID,
                                  const_cast<char *>(MODEL_IDENTIFIER));

    esp_zb_identify_cluster_cfg_t identify_cfg = {.identify_time = 0};
    esp_zb_attribute_list_t *identify = esp_zb_identify_cluster_create(&identify_cfg);

    // ZCL CO2 cluster reports as fraction of 1 (e.g. 1000 ppm -> 0.001).
    // NaN = "invalid/unknown" sentinel for the measured value.
    esp_zb_carbon_dioxide_measurement_cluster_cfg_t co2_cfg = {
        .measured_value = NAN,
        .min_measured_value = 0.0f,
        .max_measured_value = 0.01f,  // 10000 ppm — S8 range
    };
    esp_zb_attribute_list_t *co2 = esp_zb_carbon_dioxide_measurement_cluster_create(&co2_cfg);

    esp_zb_cluster_list_t *clusters = esp_zb_zcl_cluster_list_create();
    esp_zb_cluster_list_add_basic_cluster(clusters, basic, ESP_ZB_ZCL_CLUSTER_SERVER_ROLE);
    esp_zb_cluster_list_add_identify_cluster(clusters, identify, ESP_ZB_ZCL_CLUSTER_SERVER_ROLE);
    esp_zb_cluster_list_add_carbon_dioxide_measurement_cluster(clusters, co2, ESP_ZB_ZCL_CLUSTER_SERVER_ROLE);

    esp_zb_endpoint_config_t ep_cfg = {
        .endpoint = CO2_ENDPOINT,
        .app_profile_id = ESP_ZB_AF_HA_PROFILE_ID,
        .app_device_id = ESP_ZB_HA_SIMPLE_SENSOR_DEVICE_ID,
        .app_device_version = 0,
    };
    esp_zb_ep_list_add_ep(ep_list, clusters, ep_cfg);
}

void co2_task(void *)
{
    while (true) {
        if (g_co2) {
            auto r = g_co2->read();
            if (r.valid) {
                float frac = r.co2_ppm / 1000000.0f;
                if (esp_zb_lock_acquire(pdMS_TO_TICKS(500))) {
                    esp_zb_zcl_set_attribute_val(
                        CO2_ENDPOINT, ESP_ZB_ZCL_CLUSTER_ID_CARBON_DIOXIDE_MEASUREMENT, ESP_ZB_ZCL_CLUSTER_SERVER_ROLE,
                        ESP_ZB_ZCL_ATTR_CARBON_DIOXIDE_MEASUREMENT_MEASURED_VALUE_ID, &frac, false);
                    esp_zb_lock_release();
                    ESP_LOGI(TAG, "CO2: %u ppm", r.co2_ppm);
                }
            }
        }
        vTaskDelay(pdMS_TO_TICKS(CO2_REPORT_PERIOD_MS));
    }
}
// ---------------------------------------------------------------------------
#endif  // GALOPED_CO2

// --- Drive (VID6608) Zigbee endpoints --------------------------------------
constexpr uint8_t DRIVE_1_ENDPOINT = 20;
constexpr uint8_t DRIVE_2_ENDPOINT = 21;
constexpr uint16_t DRIVE_CLUSTER_ID = 0xFC10;         // manufacturer-specific
constexpr uint16_t DRIVE_ATTR_POSITION_ID = 0x0000;   // S32, RW, reportable
constexpr uint16_t DRIVE_ATTR_MAX_STEPS_ID = 0x0001;  // U16, RO
constexpr uint16_t DRIVE_ATTR_IS_MOVING_ID = 0x0002;  // BOOL, RO, reportable
constexpr uint8_t DRIVE_CMD_RESET = 0x00;
constexpr uint32_t POSITION_REPORT_PERIOD_MS = 500;

esp_timer_handle_t g_drive_report_timer = nullptr;

esp32_vid6608_rmt *drive_for_endpoint(uint8_t ep)
{
    if (ep == DRIVE_1_ENDPOINT) {
        return g_drive_1.get();
    }
    if (ep == DRIVE_2_ENDPOINT) {
        return g_drive_2.get();
    }
    return nullptr;
}

void apply_drive_attr(const esp_zb_zcl_set_attr_value_message_t *msg, esp32_vid6608_rmt *drive)
{
    if (msg->info.cluster == ESP_ZB_ZCL_CLUSTER_ID_ANALOG_OUTPUT) {
        if (msg->attribute.id == ESP_ZB_ZCL_ATTR_ANALOG_OUTPUT_PRESENT_VALUE_ID) {
            float v = *reinterpret_cast<float *>(msg->attribute.data.value);
            int32_t steps = static_cast<int32_t>(v + 0.5f);
            ESP_LOGI(TAG, "EP %u AO PresentValue=%.1f -> setPos(%ld)", msg->info.dst_endpoint, v, (long)steps);
            drive->setPos(steps);
        }
    } else if (msg->info.cluster == DRIVE_CLUSTER_ID) {
        if (msg->attribute.id == DRIVE_ATTR_POSITION_ID) {
            int32_t v = *reinterpret_cast<int32_t *>(msg->attribute.data.value);
            ESP_LOGI(TAG, "EP %u Position=%ld", msg->info.dst_endpoint, (long)v);
            drive->setPos(v);
        }
    }
}

void drive_reset_task(void *arg)
{
    auto *drive = static_cast<esp32_vid6608_rmt *>(arg);
    ESP_LOGI(TAG, "Drive reset: zero() begin");
    drive->zero();
    ESP_LOGI(TAG, "Drive reset: zero() done");
    vTaskDelete(nullptr);
}

void handle_custom_cmd(const esp_zb_zcl_custom_cluster_command_message_t *msg)
{
    if (!msg || msg->info.cluster != DRIVE_CLUSTER_ID) {
        return;
    }
    auto *drive = drive_for_endpoint(msg->info.dst_endpoint);
    if (!drive) {
        return;
    }
    switch (msg->info.command.id) {
    case DRIVE_CMD_RESET:
        ESP_LOGI(TAG, "EP %u: reset command", msg->info.dst_endpoint);
        // zero() blocks for the full sweep; run in its own task to keep Zigbee responsive
        xTaskCreate(drive_reset_task, "drv_reset", 3072, drive, 4, nullptr);
        break;
    default:
        ESP_LOGW(TAG, "EP %u: unknown custom cmd 0x%02x", msg->info.dst_endpoint, msg->info.command.id);
        break;
    }
}

void add_drive_endpoint(esp_zb_ep_list_t *ep_list, uint8_t endpoint, esp32_vid6608_rmt &drive)
{
    esp_zb_basic_cluster_cfg_t basic_cfg = {
        .zcl_version = ESP_ZB_ZCL_BASIC_ZCL_VERSION_DEFAULT_VALUE,
        .power_source = ESP_ZB_ZCL_BASIC_POWER_SOURCE_MAINS_SINGLE_PHASE,
    };
    esp_zb_attribute_list_t *basic = esp_zb_basic_cluster_create(&basic_cfg);
    esp_zb_basic_cluster_add_attr(basic, ESP_ZB_ZCL_ATTR_BASIC_MANUFACTURER_NAME_ID,
                                  const_cast<char *>(MANUFACTURER_NAME));
    esp_zb_basic_cluster_add_attr(basic, ESP_ZB_ZCL_ATTR_BASIC_MODEL_IDENTIFIER_ID,
                                  const_cast<char *>(MODEL_IDENTIFIER));

    esp_zb_identify_cluster_cfg_t identify_cfg = {
        .identify_time = 0,
    };
    esp_zb_attribute_list_t *identify = esp_zb_identify_cluster_create(&identify_cfg);

    esp_zb_analog_output_cluster_cfg_t ao_cfg = {
        .out_of_service = false,
        .present_value = static_cast<float>(drive.getCurrentPosition()),
        .status_flags = 0,
    };
    esp_zb_attribute_list_t *ao = esp_zb_analog_output_cluster_create(&ao_cfg);

    int32_t init_pos = drive.getCurrentPosition();
    uint16_t init_max = drive.getMaxSteps();
    uint8_t init_moving = 0;
    esp_zb_attribute_list_t *custom = esp_zb_zcl_attr_list_create(DRIVE_CLUSTER_ID);
    esp_zb_custom_cluster_add_custom_attr(custom, DRIVE_ATTR_POSITION_ID, ESP_ZB_ZCL_ATTR_TYPE_S32,
                                          ESP_ZB_ZCL_ATTR_ACCESS_READ_WRITE | ESP_ZB_ZCL_ATTR_ACCESS_REPORTING,
                                          &init_pos);
    esp_zb_custom_cluster_add_custom_attr(custom, DRIVE_ATTR_MAX_STEPS_ID, ESP_ZB_ZCL_ATTR_TYPE_U16,
                                          ESP_ZB_ZCL_ATTR_ACCESS_READ_ONLY, &init_max);
    esp_zb_custom_cluster_add_custom_attr(custom, DRIVE_ATTR_IS_MOVING_ID, ESP_ZB_ZCL_ATTR_TYPE_BOOL,
                                          ESP_ZB_ZCL_ATTR_ACCESS_READ_ONLY | ESP_ZB_ZCL_ATTR_ACCESS_REPORTING,
                                          &init_moving);

    esp_zb_cluster_list_t *clusters = esp_zb_zcl_cluster_list_create();
    esp_zb_cluster_list_add_basic_cluster(clusters, basic, ESP_ZB_ZCL_CLUSTER_SERVER_ROLE);
    esp_zb_cluster_list_add_identify_cluster(clusters, identify, ESP_ZB_ZCL_CLUSTER_SERVER_ROLE);
    esp_zb_cluster_list_add_analog_output_cluster(clusters, ao, ESP_ZB_ZCL_CLUSTER_SERVER_ROLE);
    esp_zb_cluster_list_add_custom_cluster(clusters, custom, ESP_ZB_ZCL_CLUSTER_SERVER_ROLE);

    esp_zb_endpoint_config_t ep_cfg = {
        .endpoint = endpoint,
        .app_profile_id = ESP_ZB_AF_HA_PROFILE_ID,
        .app_device_id = ESP_ZB_HA_LEVEL_CONTROLLABLE_OUTPUT_DEVICE_ID,
        .app_device_version = 0,
    };
    esp_zb_ep_list_add_ep(ep_list, clusters, ep_cfg);
}

void drive_report_tick(void *)
{
    struct {
        uint8_t ep;
        esp32_vid6608_rmt *drive;
    } entries[] = {
        {DRIVE_1_ENDPOINT, g_drive_1.get()},
        {DRIVE_2_ENDPOINT, g_drive_2.get()},
    };

    if (!esp_zb_lock_acquire(pdMS_TO_TICKS(100))) {
        return;
    }
    for (auto &e : entries) {
        if (!e.drive) {
            continue;
        }
        float pv = static_cast<float>(e.drive->getCurrentPosition());
        int32_t pos = e.drive->getCurrentPosition();
        uint8_t moving = e.drive->isMoving() ? 1 : 0;

        esp_zb_zcl_set_attribute_val(e.ep, ESP_ZB_ZCL_CLUSTER_ID_ANALOG_OUTPUT, ESP_ZB_ZCL_CLUSTER_SERVER_ROLE,
                                     ESP_ZB_ZCL_ATTR_ANALOG_OUTPUT_PRESENT_VALUE_ID, &pv, false);
        esp_zb_zcl_set_attribute_val(e.ep, DRIVE_CLUSTER_ID, ESP_ZB_ZCL_CLUSTER_SERVER_ROLE, DRIVE_ATTR_POSITION_ID,
                                     &pos, false);
        esp_zb_zcl_set_attribute_val(e.ep, DRIVE_CLUSTER_ID, ESP_ZB_ZCL_CLUSTER_SERVER_ROLE, DRIVE_ATTR_IS_MOVING_ID,
                                     &moving, false);
    }
    esp_zb_lock_release();
}

void start_drive_reporter()
{
    esp_timer_create_args_t args = {};
    args.callback = &drive_report_tick;
    args.dispatch_method = ESP_TIMER_TASK;
    args.name = "drive_rpt";
    ESP_ERROR_CHECK(esp_timer_create(&args, &g_drive_report_timer));
    ESP_ERROR_CHECK(esp_timer_start_periodic(g_drive_report_timer, POSITION_REPORT_PERIOD_MS * 1000));
}
// ---------------------------------------------------------------------------

void apply_light_attr(const esp_zb_zcl_set_attr_value_message_t *msg)
{
    switch (msg->info.cluster) {
    case ESP_ZB_ZCL_CLUSTER_ID_ON_OFF:
        if (msg->attribute.id == ESP_ZB_ZCL_ATTR_ON_OFF_ON_OFF_ID) {
            g_led->set_on(*reinterpret_cast<bool *>(msg->attribute.data.value));
        }
        break;

    case ESP_ZB_ZCL_CLUSTER_ID_LEVEL_CONTROL:
        if (msg->attribute.id == ESP_ZB_ZCL_ATTR_LEVEL_CONTROL_CURRENT_LEVEL_ID) {
            g_led->set_brightness(*reinterpret_cast<uint8_t *>(msg->attribute.data.value));
        }
        break;

    case ESP_ZB_ZCL_CLUSTER_ID_COLOR_CONTROL: {
        if (msg->attribute.id == ESP_ZB_ZCL_ATTR_COLOR_CONTROL_CURRENT_X_ID) {
            uint16_t x16 = *reinterpret_cast<uint16_t *>(msg->attribute.data.value);
            g_led->set_xy(x16, g_led->color_y());
        } else if (msg->attribute.id == ESP_ZB_ZCL_ATTR_COLOR_CONTROL_CURRENT_Y_ID) {
            uint16_t y16 = *reinterpret_cast<uint16_t *>(msg->attribute.data.value);
            g_led->set_xy(g_led->color_x(), y16);
        }
        break;
    }

    default:
        break;
    }
}

void apply_attr(const esp_zb_zcl_set_attr_value_message_t *msg)
{
    if (!msg) {
        return;
    }
    if (msg->info.dst_endpoint == HA_ENDPOINT) {
        if (g_led) {
            apply_light_attr(msg);
        }
        return;
    }
    if (auto *drive = drive_for_endpoint(msg->info.dst_endpoint)) {
        apply_drive_attr(msg, drive);
    }
}

esp_err_t zb_action_handler(esp_zb_core_action_callback_id_t cb_id, const void *msg)
{
    switch (cb_id) {
    case ESP_ZB_CORE_SET_ATTR_VALUE_CB_ID:
        apply_attr(static_cast<const esp_zb_zcl_set_attr_value_message_t *>(msg));
        break;
    case ESP_ZB_CORE_CMD_CUSTOM_CLUSTER_REQ_CB_ID:
        handle_custom_cmd(static_cast<const esp_zb_zcl_custom_cluster_command_message_t *>(msg));
        break;
    default:
        break;
    }
    return ESP_OK;
}

void bdb_start_commissioning_void(uint8_t mode)
{
    esp_zb_bdb_start_top_level_commissioning(mode);
}

void log_network_info(const char *event)
{
    esp_zb_ieee_addr_t ext_pan_id;
    esp_zb_get_extended_pan_id(ext_pan_id);
    ESP_LOGI(TAG,
             "%s: short=0x%04x pan=0x%04x channel=%u "
             "ext_pan=%02x:%02x:%02x:%02x:%02x:%02x:%02x:%02x",
             event, esp_zb_get_short_address(), esp_zb_get_pan_id(), esp_zb_get_current_channel(), ext_pan_id[7],
             ext_pan_id[6], ext_pan_id[5], ext_pan_id[4], ext_pan_id[3], ext_pan_id[2], ext_pan_id[1], ext_pan_id[0]);
}
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
extern "C" void app_main()
{
    ESP_LOGI(TAG, "App startup");
    ESP_LOGI(TAG, "Config: model %s, axis %d", GALOPED_MODEL, GALOPED_AXIS);

    ESP_ERROR_CHECK(nvs_flash_init());

    esp_zb_platform_config_t platform = {};
    platform.radio_config.radio_mode = ZB_RADIO_MODE_NATIVE;
    platform.host_config.host_connection_mode = ZB_HOST_CONNECTION_MODE_NONE;
    ESP_ERROR_CHECK(esp_zb_platform_config(&platform));

    // Activate drives
    // All devices have at least 1
    ESP_LOGI(TAG, "Init: drive 1");
    esp32_vid6608_rmt::Config cfg_1{
        .stepPin = static_cast<gpio_num_t>(CONFIG_GALOPED_DRIVE_1_STEP_GPIO),
        .dirPin = static_cast<gpio_num_t>(CONFIG_GALOPED_DRIVE_1_DIR_GPIO),
        .maxSteps = CONFIG_GALOPED_DRIVE_1_MAX_STEPS,
    };
    g_drive_1 = std::make_unique<esp32_vid6608_rmt>(cfg_1);

#if GALOPED_AXIS > 1
    // Devices with 2+
    ESP_LOGI(TAG, "Init: drive 2");
    esp32_vid6608_rmt::Config cfg_2{
        .stepPin = static_cast<gpio_num_t>(CONFIG_GALOPED_DRIVE_2_STEP_GPIO),
        .dirPin = static_cast<gpio_num_t>(CONFIG_GALOPED_DRIVE_2_DIR_GPIO),
        .maxSteps = CONFIG_GALOPED_DRIVE_2_MAX_STEPS,
    };
    g_drive_2 = std::make_unique<esp32_vid6608_rmt>(cfg_2);
#endif

    if (g_drive_1) {
        g_drive_1->zero();
    }
    if (g_drive_2) {
        g_drive_2->zero();
    }

    g_led = std::make_unique<RgbLed>(LED_GPIO, SPI2_HOST, LED_COUNT);
    ESP_ERROR_CHECK(g_led->init());

    g_button = std::make_unique<Button>(BUTTON_GPIO, LONG_PRESS_MS);
    g_button->on_long_press(factory_reset);
    ESP_ERROR_CHECK(g_button->init());

#if GALOPED_CLIMATE
    ESP_LOGI(TAG, "Init: climate sensor");
    g_climate = std::make_unique<ClimateSensor>(I2C_SDA_GPIO, I2C_SCL_GPIO);
    if (g_climate->init() != ESP_OK) {
        ESP_LOGE(TAG, "Climate sensor init failed; endpoint will not be added");
        g_climate.reset();
    }
#endif

#if GALOPED_CO2
    ESP_LOGI(TAG, "Init: SenseAir S8");
    g_co2 = std::make_unique<SenseAirS8>(S8_UART_PORT, S8_TX_GPIO, S8_RX_GPIO);
    if (g_co2->init() != ESP_OK) {
        ESP_LOGE(TAG, "SenseAir S8 init failed; endpoint will not be added");
        g_co2.reset();
    }
#endif

    xTaskCreate(zb_task, "zb_main", 4096, nullptr, 5, nullptr);
}

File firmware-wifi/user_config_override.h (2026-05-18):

/*
  user_config_override.h - user configuration overrides my_user_config.h for Tasmota

  Copyright (C) 2021  Theo Arends

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
  You should have received a copy of the GNU General Public License
  along with this program.  If not, see <http://www.gnu.org/licenses/>.
*/

#ifndef _USER_CONFIG_OVERRIDE_H_
#define _USER_CONFIG_OVERRIDE_H_

/*****************************************************************************************************\
 * USAGE:
 *   To modify the stock configuration without changing the my_user_config.h file:
 *   (1) copy this file to "user_config_override.h" (It will be ignored by Git)
 *   (2) define your own settings below
 *
 ******************************************************************************************************
 * ATTENTION:
 *   - Changes to SECTION1 PARAMETER defines will only override flash settings if you change define CFG_HOLDER.
 *   - Expect compiler warnings when no ifdef/undef/endif sequence is used.
 *   - You still need to update my_user_config.h for major define USE_MQTT_TLS.
 *   - All parameters can be persistent changed online using commands via MQTT, WebConsole or Serial.
\*****************************************************************************************************/

// Customizations, if any
#if __has_include("user/galoped.h")
	#include "user/galoped.h"
#endif

// Main Galoped project defines
#undef PROJECT
#define PROJECT "galoped"

#undef MQTT_TOPIC
#define MQTT_TOPIC PROJECT "_%06X"

#undef FRIENDLY_NAME
#define FRIENDLY_NAME "Galoped"

// Enabke custom Galoped UI (not part of original Tasmota)
#define USE_GALOPED

// Advanced animation modules for RGB
#define USE_BERRY_ANIMATION

// Required features for this project:
// [I2cDriver43] Enable AHT20/AM2301B instead of AHT1x humidity and temperature sensor (I2C address 0x38) (+0k8 code)
#ifndef USE_AHT2x
    #define USE_AHT2x
#endif
// [I2cDriver10] Enable BMP085/BMP180/BMP280/BME280 sensors (I2C addresses 0x76 and 0x77) (+4k4 code)
#ifndef USE_BMP
    #define USE_BMP
#endif
// Add support for SenseAir K30, K70 and S8 CO2 sensor (+2k3 code)
#ifndef USE_SENSEAIR
    #define USE_SENSEAIR
#endif


// Enable WS2812 leds number (any HW model)
#undef WS2812_LEDS
// If RGB backlight is used, it will have 40 LED's
#define WS2812_LEDS 40

// Template defaults, apply on flash reset
// Apply default backlight options, i.e. color and level
// Default color: #4D3912
#define GALOPED_TEMPLATE_CMD "Power1 ON|Dimmer1 30|Color1 4D3912"

// Define chipset here
#if CONFIG_IDF_TARGET_ESP32
#define GALOPED_PLATFORM_ESP32
#elif CONFIG_IDF_TARGET_ESP32C6
#define GALOPED_PLATFORM_ESP32C6
// Disable RMT for TasmotaLED on c6 platform (only 2 RMT channels)
#define TASMOTALED_HARDWARE_RMT 0
#else
#error "Unsupported platform"
#endif

// Defined Galoped models for pre-configuration
// Axis count (1 or 2)
#ifndef GALOPED_AXIS
#   define GALOPED_AXIS 1  // Default is single-axis
#endif

// Add support for VID6608 Automotive analog gauge driver (+0k7 code)
#define USE_VID6608

// Use HW RMT driver
#define VID6608_RMT 1

// Reset VID6608 on init (default: true), change if you control this manually
// Starting from 2026-04-03: reset is controlled from FW Galoped driver
#define VID6608_RESET_ON_INIT 0

// The bi-axial version with BKA30D-R5 require some precise steps-tuning,
// as it has jitter at the end-stops, this can cause resolution drop
#if GALOPED_AXIS == 2
#define VID6608_STEPS_1 3950 // 329.2°
#define VID6608_STEPS_2 3295 // 274.5°
// The BKA30D-R5 drive has to be pulled up a bit
#define VID6608_ZERO_PULLUP_STEPS 5
#else
// Default steps - same for singe- and bi-axial versions, 320° + 270°
#define VID6608_STEPS_1 12 * 320
#define VID6608_STEPS_2 12 * 275
// Default is not to use additional pull-up mode
#define VID6608_ZERO_PULLUP_STEPS 0
#endif

// Backlight
#define GALOPED_BACKLIGHT_RGB 0
#define GALOPED_BACKLIGHT_RETRO 1
#ifndef GALOPED_BACKLIGHT
#   define GALOPED_BACKLIGHT GALOPED_BACKLIGHT_RGB // Default is RGB
#endif

// Generate our template (ESP32 and ESP32C6 require different)
// ESP32-WROOM32
#ifdef GALOPED_PLATFORM_ESP32
#if GALOPED_BACKLIGHT == GALOPED_BACKLIGHT_RGB
#define GALOPED_TEMPLATE_BACKLIGHT "0,1376"
#endif
#if GALOPED_BACKLIGHT == GALOPED_BACKLIGHT_RETRO
#define GALOPED_TEMPLATE_BACKLIGHT "416,0"
#endif
#if GALOPED_AXIS == 1
#define GALOPED_TEMPLATE_AXIS_2 "1,1"
#endif
#if GALOPED_AXIS == 2
#define GALOPED_TEMPLATE_AXIS_2 "12161,12193"
#endif

#define USER_TEMPLATE "{\"NAME\":\"Galoped\",\"GPIO\":[1,1,1,1,1,1,1,1,1,1," GALOPED_TEMPLATE_BACKLIGHT ",1600,1632,1,1,0,640,608,1,0,1,12160,12192,0,0,0,0," GALOPED_TEMPLATE_AXIS_2 ",32,1,1,0,0,1],\"FLAG\":0,\"BASE\":1,\"CMND\":\"" GALOPED_TEMPLATE_CMD "\"}"

#endif // GALOPED_PLATFORM_ESP32
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

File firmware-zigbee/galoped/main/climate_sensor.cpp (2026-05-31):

#include "climate_sensor.h"

#include "esp_check.h"
#include "esp_log.h"
#include "freertos/FreeRTOS.h"
#include "freertos/task.h"

static const char *TAG = "CLIMATE";

namespace
{
constexpr uint32_t I2C_FREQ_HZ = 100000;
constexpr int I2C_TIMEOUT_MS = 100;
}  // namespace

ClimateSensor::ClimateSensor(gpio_num_t sda, gpio_num_t scl, i2c_port_num_t port)
    : sda_(sda),
      scl_(scl),
      port_(port),
      bus_(nullptr),
      bmp_(nullptr),
      aht_(nullptr),
      bmp_present_(false),
      aht_present_(false),
      bmp_addr_(0),
      bmp_chip_id_(0),
      bmp_cal_{}
{
}

ClimateSensor::~ClimateSensor()
{
    if (bmp_) {
        i2c_master_bus_rm_device(bmp_);
    }
    if (aht_) {
        i2c_master_bus_rm_device(aht_);
    }
    if (bus_) {
        i2c_del_master_bus(bus_);
    }
}

void ClimateSensor::bus_scan()
{
    ESP_LOGI(TAG, "I2C scan on sda=%d scl=%d:", sda_, scl_);
    for (uint8_t addr = 0x08; addr < 0x78; ++addr) {
        if (i2c_master_probe(bus_, addr, 50) == ESP_OK) {
            ESP_LOGI(TAG, "  found 0x%02x", addr);
        }
    }
}

esp_err_t ClimateSensor::bmp280_probe(uint8_t addr)
{
    i2c_device_config_t dev_cfg = {};
    dev_cfg.dev_addr_length = I2C_ADDR_BIT_LEN_7;
    dev_cfg.scl_speed_hz = I2C_FREQ_HZ;
    dev_cfg.device_address = addr;

    i2c_master_dev_handle_t h;
    if (i2c_master_bus_add_device(bus_, &dev_cfg, &h) != ESP_OK) {
        return ESP_FAIL;
    }
    uint8_t reg = 0xD0;  // chip_id register
    uint8_t id = 0;
    esp_err_t err = i2c_master_transmit_receive(h, &reg, 1, &id, 1, I2C_TIMEOUT_MS);
    if (err != ESP_OK) {
        i2c_master_bus_rm_device(h);
        return err;
    }
    // 0x58 = BMP280, 0x60 = BME280 (same temp/pressure registers + cal layout)
    if (id != 0x58 && id != 0x60) {
        ESP_LOGW(TAG, "  0x%02x: unexpected chip_id 0x%02x", addr, id);
        i2c_master_bus_rm_device(h);
        return ESP_ERR_NOT_FOUND;
    }
    bmp_ = h;
    bmp_addr_ = addr;
    bmp_chip_id_ = id;
    ESP_LOGI(TAG, "BMP280 at 0x%02x (chip_id=0x%02x %s)", addr, id, id == 0x60 ? "BME280" : "BMP280");
    return ESP_OK;
}

esp_err_t ClimateSensor::init()
{
    i2c_master_bus_config_t bus_cfg = {};
    bus_cfg.i2c_port = port_;
    bus_cfg.sda_io_num = sda_;
    bus_cfg.scl_io_num = scl_;
    bus_cfg.clk_source = I2C_CLK_SRC_DEFAULT;
    bus_cfg.glitch_ignore_cnt = 7;
    bus_cfg.flags.enable_internal_pullup = true;
    ESP_RETURN_ON_ERROR(i2c_new_master_bus(&bus_cfg, &bus_), TAG, "i2c bus");

    bus_scan();

    // BMP280: try both possible addresses
    if (bmp280_probe(BMP280_ADDR_PRIMARY) == ESP_OK || bmp280_probe(BMP280_ADDR_ALT) == ESP_OK) {
        if (bmp280_init() == ESP_OK) {
            bmp_present_ = true;
        } else {
            ESP_LOGW(TAG, "BMP280 found but cal read failed");
        }
    } else {
        ESP_LOGW(TAG, "BMP280 not found at 0x76 or 0x77");
    }

    // AHT20
    i2c_device_config_t dev_cfg = {};
    dev_cfg.dev_addr_length = I2C_ADDR_BIT_LEN_7;
    dev_cfg.scl_speed_hz = I2C_FREQ_HZ;
    dev_cfg.device_address = AHT20_ADDR;
    if (i2c_master_bus_add_device(bus_, &dev_cfg, &aht_) == ESP_OK && aht20_init() == ESP_OK) {
        aht_present_ = true;
        ESP_LOGI(TAG, "AHT20 at 0x%02x", AHT20_ADDR);
    } else {
        ESP_LOGW(TAG, "AHT20 not responding at 0x%02x", AHT20_ADDR);
    }

    if (!bmp_present_ && !aht_present_) {
        ESP_LOGE(TAG, "Neither sensor responded on the bus");
        return ESP_ERR_NOT_FOUND;
    }
    ESP_LOGI(TAG, "init ok: bmp=%d aht=%d", bmp_present_, aht_present_);
    return ESP_OK;
}

// --- BMP280 ----------------------------------------------------------------

esp_err_t ClimateSensor::bmp280_init()
{
    uint8_t reg = 0x88;
    uint8_t cal[24];
    ESP_RETURN_ON_ERROR(i2c_master_transmit_receive(bmp_, &reg, 1, cal, sizeof(cal), I2C_TIMEOUT_MS), TAG, "cal read");

    bmp_cal_.T1 = static_cast<uint16_t>(cal[0] | (cal[1] << 8));
    bmp_cal_.T2 = static_cast<int16_t>(cal[2] | (cal[3] << 8));
    bmp_cal_.T3 = static_cast<int16_t>(cal[4] | (cal[5] << 8));
    bmp_cal_.P1 = static_cast<uint16_t>(cal[6] | (cal[7] << 8));
    bmp_cal_.P2 = static_cast<int16_t>(cal[8] | (cal[9] << 8));
    bmp_cal_.P3 = static_cast<int16_t>(cal[10] | (cal[11] << 8));
    bmp_cal_.P4 = static_cast<int16_t>(cal[12] | (cal[13] << 8));
    bmp_cal_.P5 = static_cast<int16_t>(cal[14] | (cal[15] << 8));
    bmp_cal_.P6 = static_cast<int16_t>(cal[16] | (cal[17] << 8));
    bmp_cal_.P7 = static_cast<int16_t>(cal[18] | (cal[19] << 8));
    bmp_cal_.P8 = static_cast<int16_t>(cal[20] | (cal[21] << 8));
    bmp_cal_.P9 = static_cast<int16_t>(cal[22] | (cal[23] << 8));

    // ctrl_meas: osrs_t=x1 (001), osrs_p=x1 (001), mode=normal (11) -> 0x27
    uint8_t ctrl[] = {0xF4, 0x27};
    ESP_RETURN_ON_ERROR(i2c_master_transmit(bmp_, ctrl, sizeof(ctrl), I2C_TIMEOUT_MS), TAG, "ctrl_meas");

    // config: t_sb=500ms (100), filter off (000), spi3w_en=0
    uint8_t cfg[] = {0xF5, (4 << 5)};
    return i2c_master_transmit(bmp_, cfg, sizeof(cfg), I2C_TIMEOUT_MS);
}

esp_err_t ClimateSensor::bmp280_read_raw(int32_t &t_raw, int32_t &p_raw)
{
    uint8_t reg = 0xF7;
    uint8_t buf[6];
    ESP_RETURN_ON_ERROR(i2c_master_transmit_receive(bmp_, &reg, 1, buf, sizeof(buf), I2C_TIMEOUT_MS), TAG, "bmp read");
    p_raw = (static_cast<int32_t>(buf[0]) << 12) | (static_cast<int32_t>(buf[1]) << 4) | (buf[2] >> 4);
    t_raw = (static_cast<int32_t>(buf[3]) << 12) | (static_cast<int32_t>(buf[4]) << 4) | (buf[5] >> 4);
    return ESP_OK;
}

// Bosch reference compensation; outputs t_fine for the pressure formula.
float ClimateSensor::bmp280_compensate_temp(int32_t adc_T, int32_t &t_fine)
{
    int32_t var1 =
        ((((adc_T >> 3) - (static_cast<int32_t>(bmp_cal_.T1) << 1))) * static_cast<int32_t>(bmp_cal_.T2)) >> 11;
    int32_t var2 =
        (((((adc_T >> 4) - static_cast<int32_t>(bmp_cal_.T1)) * ((adc_T >> 4) - static_cast<int32_t>(bmp_cal_.T1))) >>
          12) *
         static_cast<int32_t>(bmp_cal_.T3)) >>
        14;
    t_fine = var1 + var2;
    return ((t_fine * 5 + 128) >> 8) / 100.0f;
}
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

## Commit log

2025-11-09 Add case 3d models
    [arrow.stl, front.stl]
2025-11-09 Add retro version of Arrow and Display
    [arrow-retro.stl]
2025-11-09 Fix DEKAD case screw holes, add FCStd models
    [arrow-retro.FCStd, arrow.FCStd, front.FCStd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]
2025-11-09 Fix top case: length to bottom 33mm
    [front.FCStd, front.stl]
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2025-11-12 Expressions in arrow model, mirror in front model
    [arrow-box-2mm-hole-1.6mm.stl, arrow-box-2mm-hole-1.7mm.stl, arrow-box-2mm-hole-1.8mm.stl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]
2025-11-12 Expressions in front model used
    [front.FCStd]
2025-11-12 Expressions in front model used, add nut holes to improve assembly
    [front.FCStd]
2025-11-12 Front: motor pad changed to postament with 3mm up
    [front.FCStd, front.stl]
2025-11-12 Rework Gauge to use proper along-path filters to draw extra elements
2025-11-12 Front: update model with better M3 nuts holes
    [front.FCStd]
2025-11-12 Front: tune hole size for stepper drive
    [front.FCStd, front.stl]
2025-11-13 Add inner ring (for transparent print)
    [front.FCStd, front.stl, ring.FCStd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]
2025-11-13 Add inner ring (for transparent print) - RGB version
    [ring-rgb.FCStd, ring-rgb.stl]
2025-11-14 Ring RGB version 2 - looks better
    [ring-rgb.FCStd, ring-rgb.stl]
2025-11-14 Finalize front panel: motor place adjust, add motor holders
    [front.FCStd, front.stl]
2025-11-15 Add 1mm for motor base borders
    [front.FCStd, front.stl]
2025-11-16 Add special version for Front case: screw mounts moved to attach pegboard
    [drive-backplate.FCStd, front-prototype.FCStd, front-prototype.step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]
2025-11-28 Rework Arrow-retro, add datasheets
    [arrow2-retro.FCStd, arrow2-retro.stl, drive-backplate.stl]
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2025-11-30 Add assembly, reworked front panel with correct definition
    [dekad-assembly.FCStd, dekad-case.FCStd, dekad-glass.FCStd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]
2025-11-30 Fix object names for front-v2
    [front-v2.FCStd]
2025-11-30 Fix motor pad holes to right position, add x27-168 model
    [dekad-assembly.FCStd, front-v2.FCStd]
2025-12-04 Update assembly, back panel design
    [back.FCStd, back.stl, board.FCStd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]
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2025-12-04 Progress for back plate, add readme, test on real device
    [back.FCStd, dekad-assembly.FCStd, front-v2.FCStd]
2025-12-05 Finalize back panel: covers for S8 and Climate sensors
    [back-climate.stl, back-s8.stl, back.FCStd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]
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2025-12-05 Adjust back plate: update width of USB-C port from 5 to 5.5 mm
    [back.FCStd, back.stl]
2025-12-07 Top label model and S8 and Climate covers fixes
    [arrow2.stl, back-climate.stl, back-s8.stl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]
2025-12-07 Printed and tested back, S8 and Climate covers, back as now additional rand to keep straight
    [back-climate.stl, back-s8.stl, back.FCStd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]
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2025-12-08 Add top cover, back plate fixes
    [back-s8.stl, back.FCStd, back.stl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]
2025-12-09 Try to make 2-part LED ring
    [ring-rgb-cap.stl, ring-rgb.FCStd, ring-rgb.stl]
2025-12-09 Final version of Ring-RGB, add test for light
    [ring-rgb-cap.stl, ring-rgb.FCStd, ring-rgb.stl]
2025-12-11 Tune Ring, try to iterate with FRAM
    [ring-rgb-cap.stl, ring-rgb.FCStd]
2025-12-11 Tune USB-C connector binder
    [back.FCStd, back.stl]
2025-12-12 Rework front case to use threadded insert M2
    [front-v2.FCStd, front-v2.stl, holes-test-m2.stl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]
2025-12-12 Rework back and top case to use threadded insert M2 / M3
    [back.FCStd, back.stl, top-label.FCStd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]
2025-12-13 USB fixes dissapeared (?) in back - recreated again
    [back.FCStd, back.stl]
2025-12-13 Update ring-rgb to have larger hole for wires, as required for "retro" filament ring
    [ring-rgb.FCStd, ring-rgb.stl]
2025-12-13 Add overall device drawing, add manual
    [board.FCStd, dekad-assembly.FCStd, dekad-case.FCStd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]
2025-12-14 Tune front detail: +2mm motor holder, +3mm back holder
    [front-v2.FCStd, front-v2.stl]
2025-12-17 Front: reduce motor and case holders to 1mm, reinforce leg holders
    [front-v2.FCStd, front-v2.stl]
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2025-12-23 Update ring-rgb to have smaller wire hole
    [ring-rgb.FCStd, ring-rgb.stl]
2025-12-23 Update ring-rgb to have small markers to easier align
    [ring-rgb.FCStd, ring-rgb.stl]
2025-12-23 Case: cleanup from test, old and wrong parts, move stl files to subfolder
    [arrow-2mm.stl, arrow-box-2mm-hole-1.6mm.stl, arrow-box-2mm-hole-1.7mm.stl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]
2025-12-23 Ring: moved to single model for both versions, optimized versions for both RGB and Retro variants
    [ring-cap.stl, ring-retro.stl, ring-rgb.FCStd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]
2025-12-25 Add BambuLab studio project with print settings
    [galoped-dekad.3mf]
2025-12-26 Tune Bambu project for 3dprint
    [galoped-dekad.3mf]
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2025-12-26 Fix typo in schematic folder name
2025-12-28 Add brand new needle, to be printed with 0.2mm Nozzle
    [arrow-3.3mf, arrow-3.FCStd, arrow-3.stl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]
2025-12-28 Tune logf scale and calculations
    [arrow-3.3mf]
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2025-12-29 Reduce gap for Sensair S8 cover
    [back-s8.stl, back.FCStd]
2025-12-29 Reduce overall case holder from 32 to 31 mm
    [front-v2.FCStd, front-v2.stl]
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2026-04-06 Version 2 progress: case, bi-axis arrow, new gauges
    [Galoped-case.FCStd, arrow-double-down.step, arrow-double-top.step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]
2026-04-06 Version 2 progress: case allmost done
    [Galoped-case.FCStd, Usb-conn.FCStd, arrow-double-down.step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]
2026-04-06 Tune size and wiring for Led-rings
    [Galoped-case.FCStd, back.step, galoped-case.3mf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]
2026-04-06 Fix RGB backlight issues
    [Galoped-case.FCStd, front.step, galoped-case.3mf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]
2026-04-06 Add 270-degree version and other gauges and arrows
    [Galoped-case.FCStd, arrow-ds-alt-down.step, arrow-ds-alt-top.step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]
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2026-04-06 Add HW configuration for ESP32-C6 variant, redefine hw configs
    [galoped-case.3mf]
2026-04-06 Add ESP32-C6 Zigbee example application source
    [partitions.csv]
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2026-04-06 Upgrade FreeCAD from 1.0.2 to 1.1.0
    [Galoped-case.FCStd]
2026-04-06 RGB-Ring: try to product Ring+cap as a single part, Cap reduced 0.2 mm diameter
    [Galoped-case.FCStd, ring-rgb-with-cap.step]
2026-04-06 RGB-Ring: new version with compund cap
    [Galoped-case.FCStd]
2026-04-06 RGB-Ring: final version with compond cap (bi-material)
    [Galoped-case.FCStd, galoped-ring-rgb.3mf, ring-rgb-with-cap.step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]
2026-04-06 Add Back-plate number, S8-Cover, enlarge Ring-RGB wire holes
    [Galoped-case.FCStd, back-plate.step, cover-s8.step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]
2026-04-06 Finish S8 and Climate covers
    [Galoped-case.FCStd, back.step, cover-climate.step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]
2026-04-06 Tune case details and firmware updates
    [Galoped-case.FCStd, back.step, btn.step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]
2026-04-06 Tune MAC address display
    [galoped-case.3mf]
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2026-04-06 Rework Galoped as separate files; add CO2 position driver, add auto RGB backlight color
2026-04-06 Galoped: rework options selector for RGB mode
    [galoped-ring-rgb.3mf]
2026-04-06 Galoped: use FRAM to save and restore position for all configured drives
    [galoped-ring-rgb.3mf]
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2026-04-06 Rework firmware model management, now driven by defines only, no external profiles required
    [user_config_override.h]
2026-04-06 Fix backlight model for ESP32c6
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2026-04-06 Readme: fix foto for 3D Printer version
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2026-04-07 Galoped: fix updates from printer too frequent, and broken check
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2026-04-14 Release 2.0
    This version is for Galoped-dekad version 2.0 PCB and hardware:
    * Complete new case parts with optimized design:
    * Backlight and main part are assembled before case installation (significally reduces assembly effort)
    * Improved structure stability
    * Only one PCB for now is required, drive enclosure is part of case for now
    * Fixed design issues for PCB (missing pulldown resistors, connectors redesign)
    * New USB-C power socket with USB-C-C cables support
    * Complete rework of RGB backlight, removed LED artifacts and glare
    * Complete firmware rework (autoexec.bat is not required anymore, fully integrated logic and UI)
    Firmaware changes:
    * Migrate to Tasmota 15.3.0.3
    * Firm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
2026-04-14 Docs: fix main page image, fix assembly page
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2026-05-21 Zigbee: fix LED color control
    [button.cpp, galoped.cpp, rgb_led.cpp]
2026-05-21 Github: workflow fixes for Zigbee
    [galoped.cpp]
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2026-05-31 Zigbee2mqtt converter fixes - fix brightness issues
    [rgb_led.cpp]
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

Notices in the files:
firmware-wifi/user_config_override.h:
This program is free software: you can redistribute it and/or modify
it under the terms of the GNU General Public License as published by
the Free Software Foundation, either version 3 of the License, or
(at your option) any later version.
